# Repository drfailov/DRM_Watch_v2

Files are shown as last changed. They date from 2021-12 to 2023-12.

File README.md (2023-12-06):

<!-- For new line: \ -->
<!-- Picture: <img src="Photos/" width="300"/>  -->

# About project DRM Watch v2
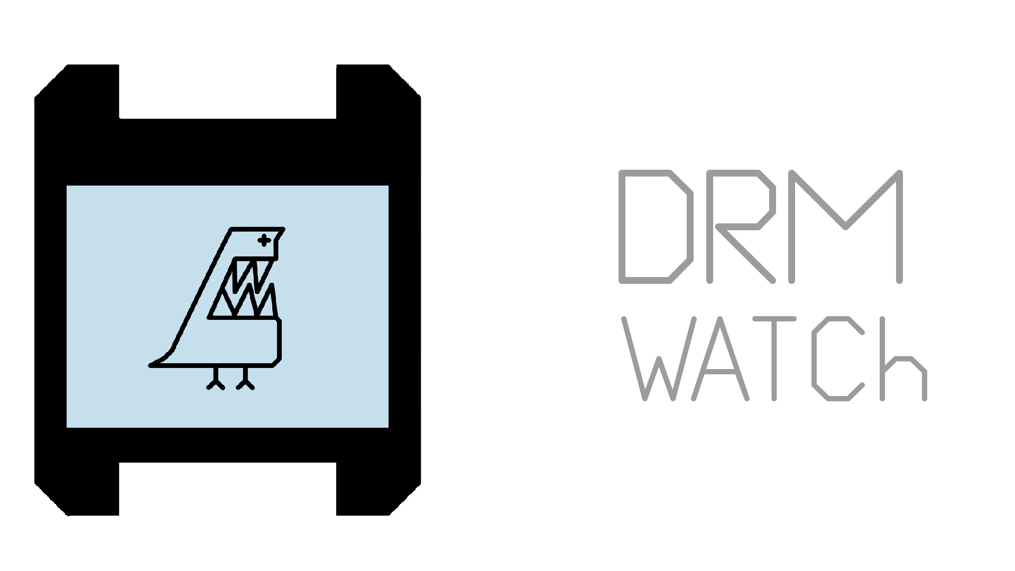
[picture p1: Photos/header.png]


Arduino-based watch with Nokia 1280 LCD. \
Main challenge of this project is packing as much
as possible stuff inside Arduino Nano with its 32KB of memory and 2KB RAM.\
Programming contributions made by <b>Dr. Failov</b>.
<!--Hardware design is made by <b>MeltemiOS</b>. -->

## About project > Features
- Low power consumption, while screen is always showing time;
- Charging over USB, battery status indication;
- Easy to get components needed to assemble;
- For now firmware is stable enough to use device daily;
- Case fits to default 20mm watch bands;
- No need to disassemble device for firmwate update;
- Device easily can be used as arduino playground: battery powered, equipped with 2 buttons, display, buzzer;
- Water-resistance up to 0 meters :)
- Multiple Watchfaces, can be changed from menu;
- 2-button controlled graphic menu allow access to all functions;
- Alarm, can be set from menu;
- Monophonic melodies, can be used as alarm or played from menu;
- Stopwatch, can be accessed from menu;
- Time can be set from menu;
- Silent mode can be set from menu. Disable all sounds except alarm;
- Sound of pressing buttons can be set from menu;
- If needed, you can reboot watch by long-pressing "Up" button on watchface;
- Flip screen allows you to choose between left-hand and right-hand buttons position;
- Random decision helper: Zrada-Peremoga;
- Screen "About" shows credits and firmware version. Long-press will show you some debug information.

## About project > Photos of device
I have assembled few watches and using it as my everyday watch for over a year. 
My device has battery about 80mAh capacity and works about 5 days for one charge.
Other device with 250mAh battery lasts about 2 weeks for one charge.
According to my tests, time error can't be noticed in 1 mounth perspective: RTC is very precise.

Here's some photos of watches with SLS case: 
<p align="center">
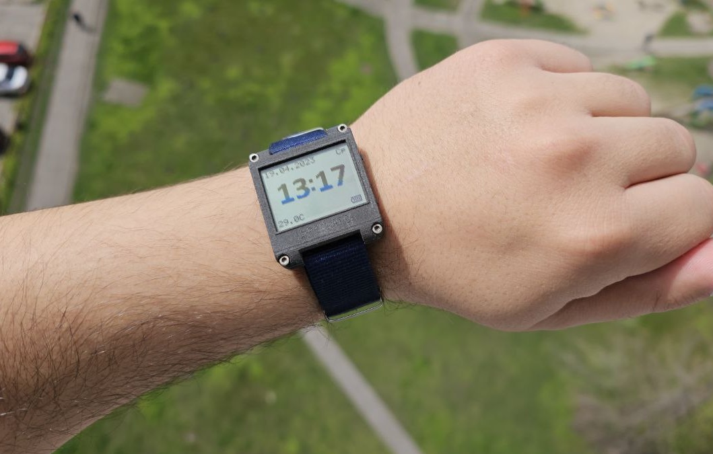
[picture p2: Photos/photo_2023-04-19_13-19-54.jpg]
 
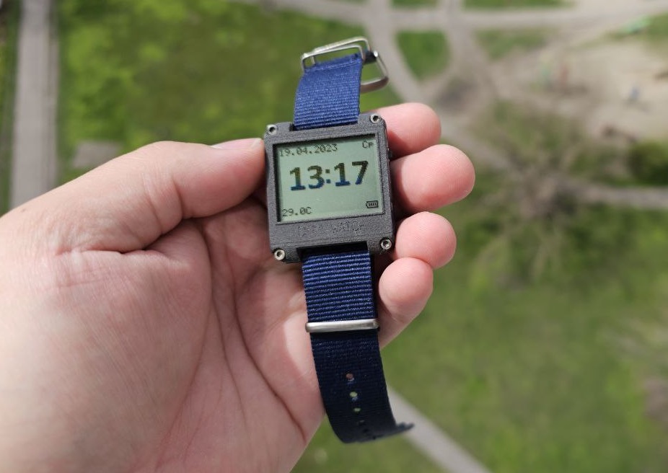
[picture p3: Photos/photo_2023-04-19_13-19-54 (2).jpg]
 
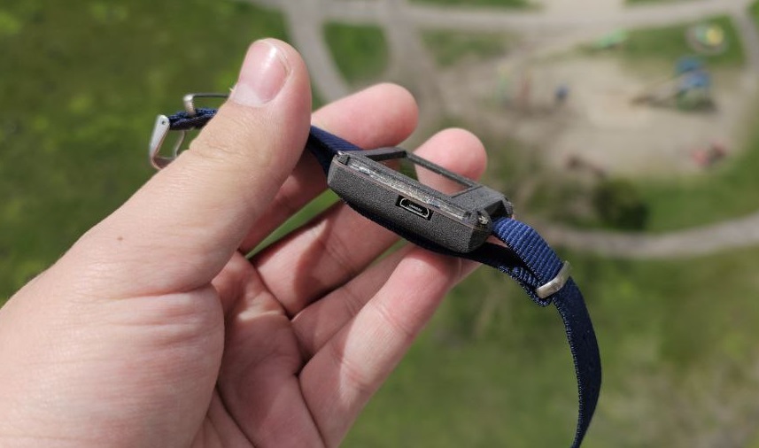
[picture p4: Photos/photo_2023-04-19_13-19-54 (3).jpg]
 
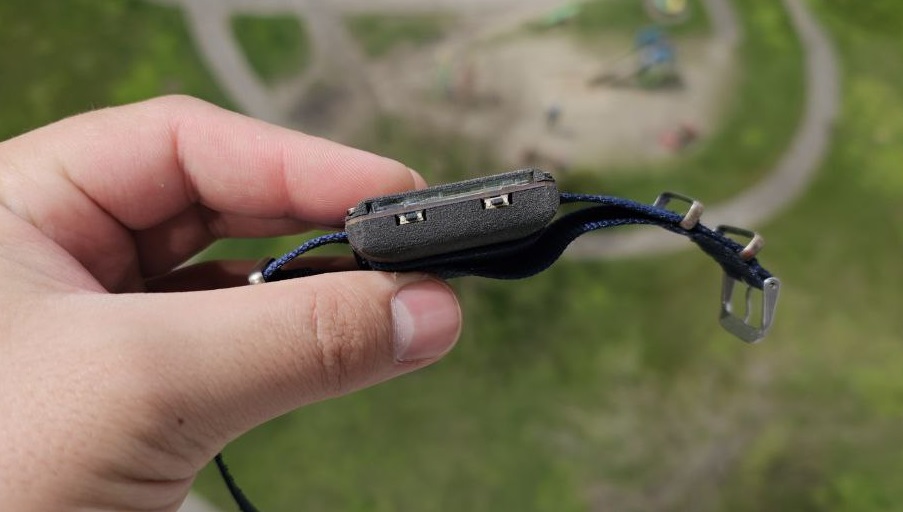
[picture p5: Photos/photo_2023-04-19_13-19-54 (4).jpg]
 
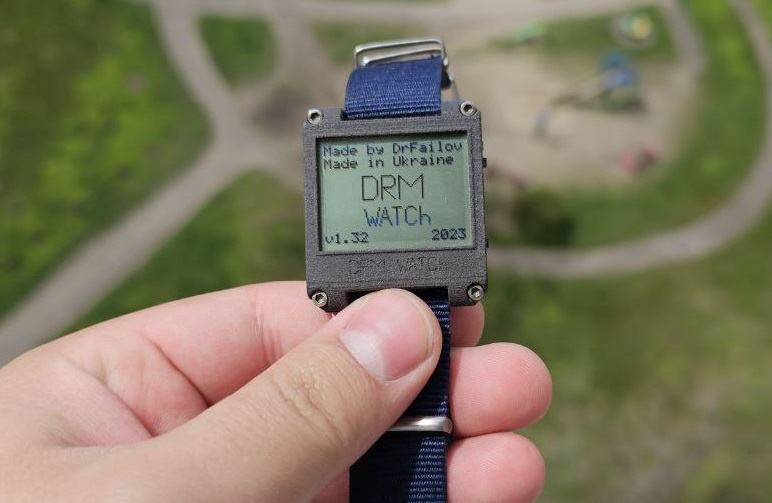
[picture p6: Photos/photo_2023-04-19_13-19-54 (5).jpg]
 
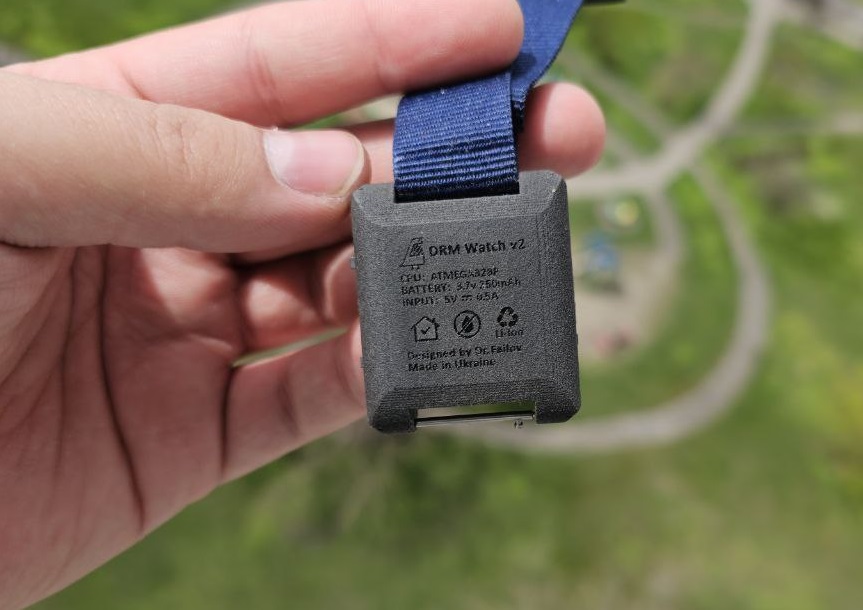
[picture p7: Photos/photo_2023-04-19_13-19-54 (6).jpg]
 
</p>

And some photos of watches with FDM case:
<p align="center">
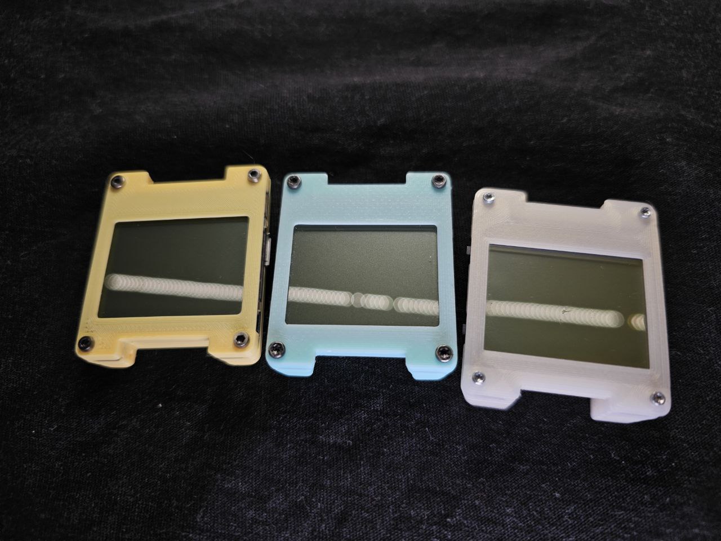
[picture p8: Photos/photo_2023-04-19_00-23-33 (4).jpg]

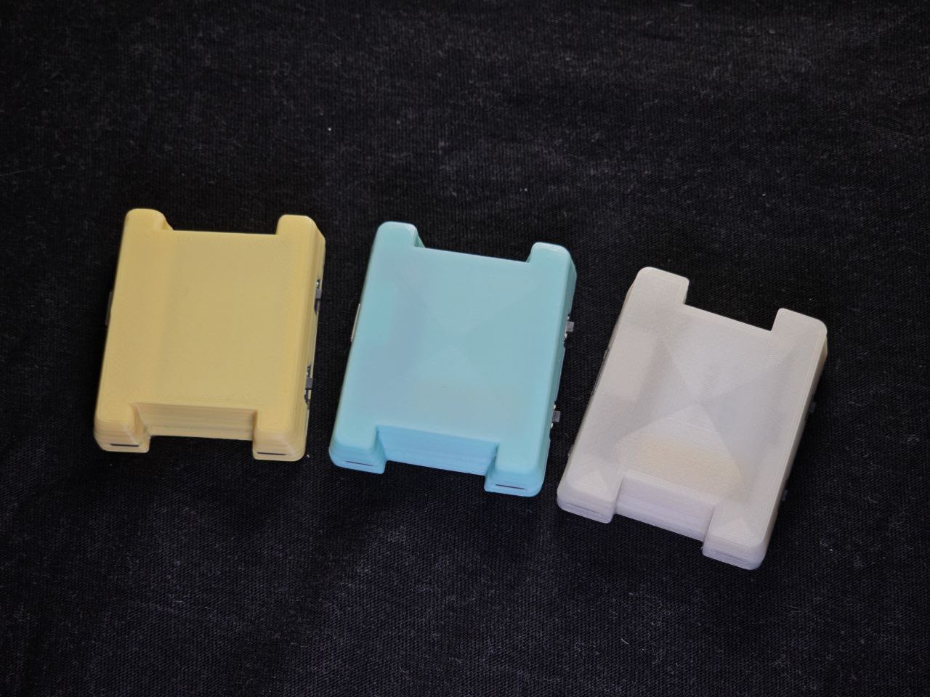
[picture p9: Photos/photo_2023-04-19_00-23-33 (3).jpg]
 
</p>

## About project > Video overview
YouTube video with device overview: 

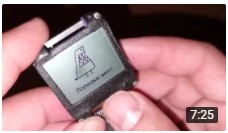
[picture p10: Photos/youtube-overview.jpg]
DRM Watch v2 Overview
[](https://youtu.be/VYrUO039QUw) 
<p align="center">https://youtu.be/VYrUO039QUw </p>

## About project > Typical problems
Regarding watches: they have two typical problems.
1) Water. There is essentially no protection against water, so you need to avoid getting water on them, and especially inside.
2) Statics. Static can occur when plugged into a charger, or when putting on/taking off a sweater or other synthetic clothing.
Therefore, the watch must either be removed for a while, or move slowly so that static in large quantities does not have time to form.

If static has already affected the clock, then:
- usually the display suffers first, there are artifacts. For six months, I had this happen 5 times. 
In this case, the watch can be reset (hold down the top button until you see the loading animation).
- A complete freeze of the controller may occur up to the impossibility of rebooting. 
Then you need to disassemble the watch and reconnect the battery, or wait for the battery to be FULLY discharged and then charge the fully discharged watch.
In the meantime, time will slip. (In my six months of use, this was 1 time).
- The controller may also be affected. (in theory, in practice I haven’t had this for half a year of use)
In this case, it needs to be replaced with a new one (solder the microcircuit)

## About project > Overview of Watchfaces
You can change set of watchfaces in firmware. More info about it in "Software" block.

### Watchface "DRM Watch"
The first watchface in project, back from 2016. Inspired by iPod nano. 
Takes about <b>486 bytes</b> of FLASH memory. 
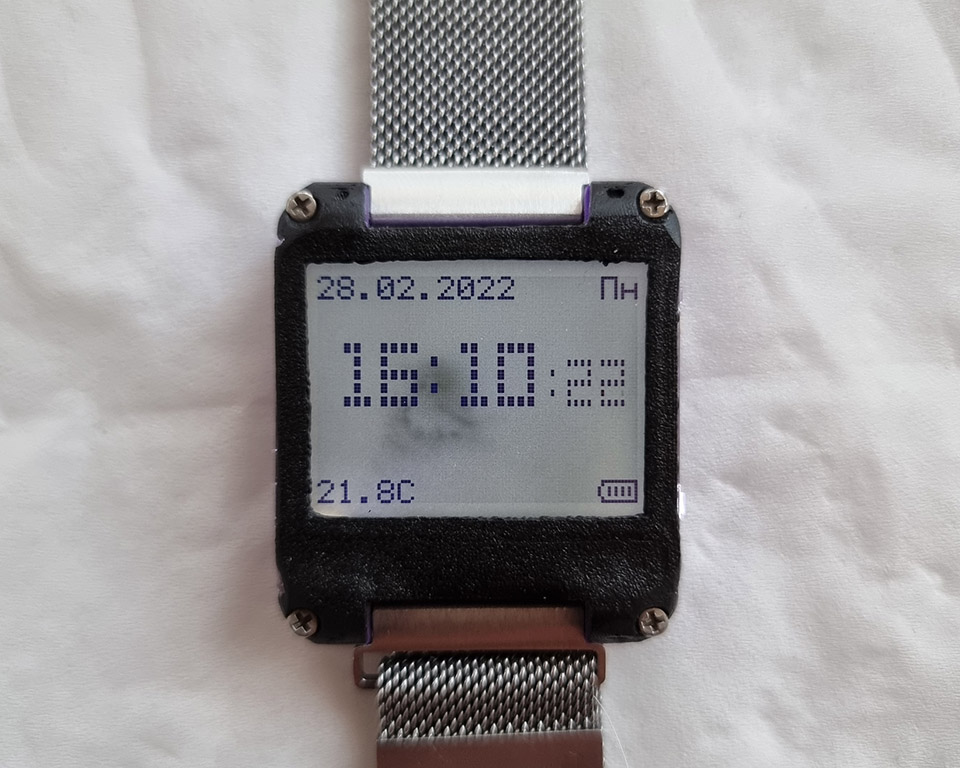
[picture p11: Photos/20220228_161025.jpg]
<p align="center">
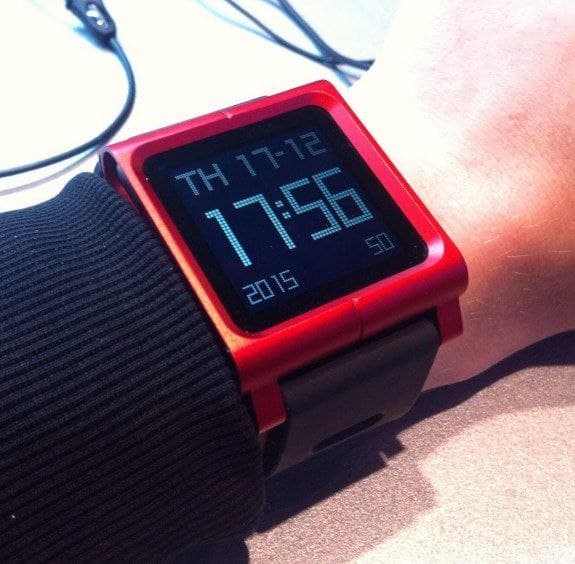
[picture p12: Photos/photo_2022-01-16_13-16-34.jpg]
</p>

### Watchface "DRM Lite"
"DRM Watch" without seconds. \
Designed by <b>Dr. Failov</b>.
Takes about <b>430 bytes</b> of FLASH memory. 
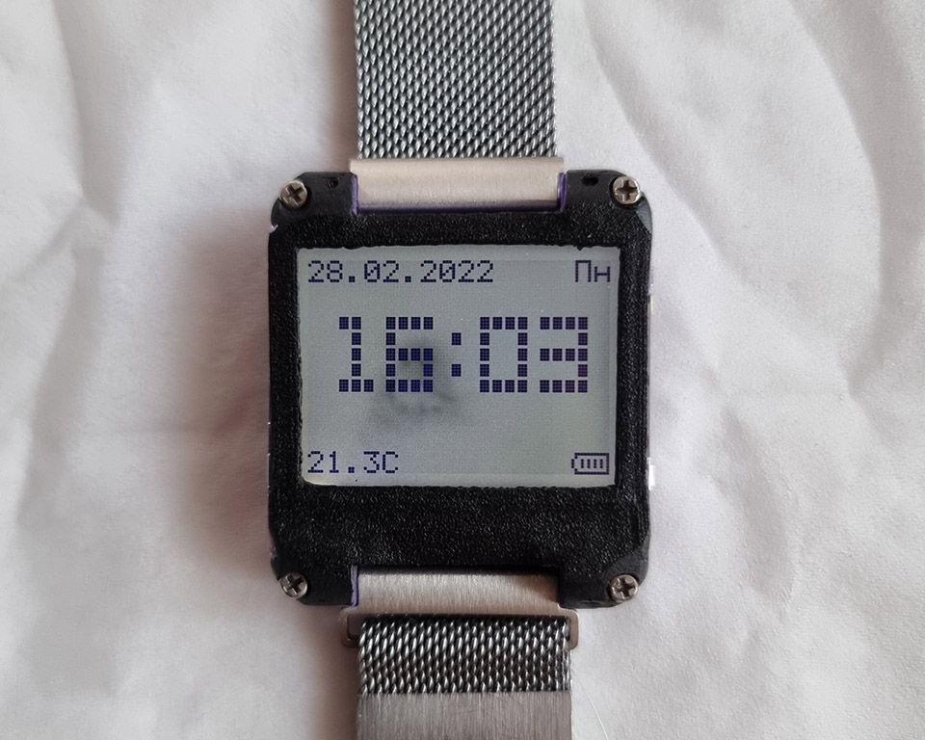
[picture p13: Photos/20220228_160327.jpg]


### Watchface "Nomens"
Inspired by Siemens screensaver and Nokia home screen.
Takes about <b>666 bytes</b> of FLASH memory. 
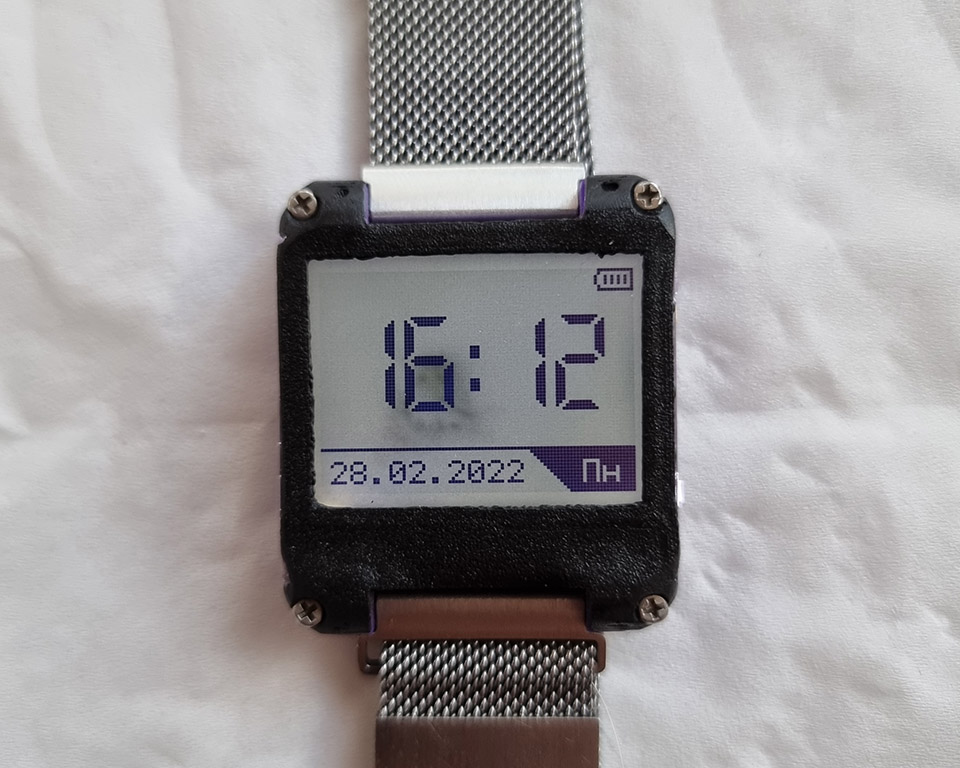
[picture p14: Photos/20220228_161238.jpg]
<p align="center">
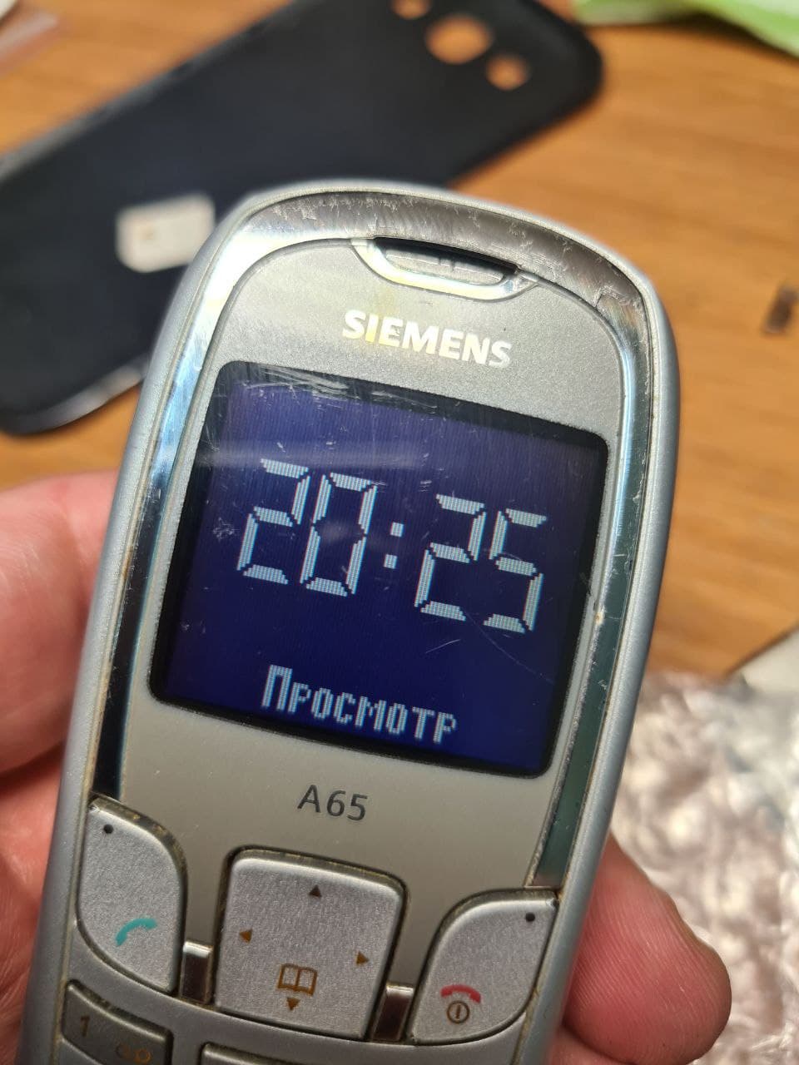
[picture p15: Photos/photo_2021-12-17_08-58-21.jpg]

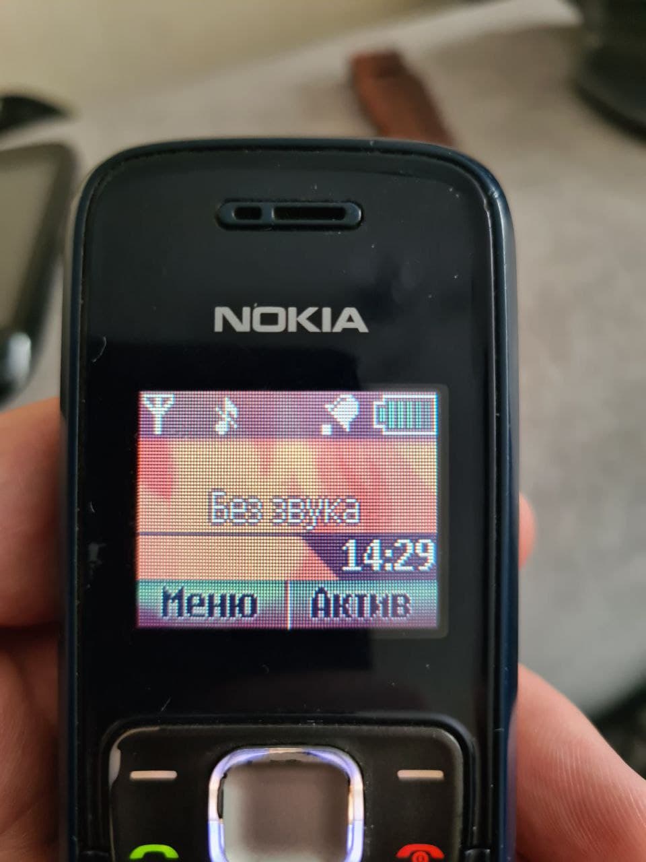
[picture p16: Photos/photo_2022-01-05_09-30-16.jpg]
</p>

### Watchface "Zubat"
Project logo on watchface.\
Designed by <b>Dr. Failov</b>.
Takes about <b>336 bytes</b> of FLASH memory. 
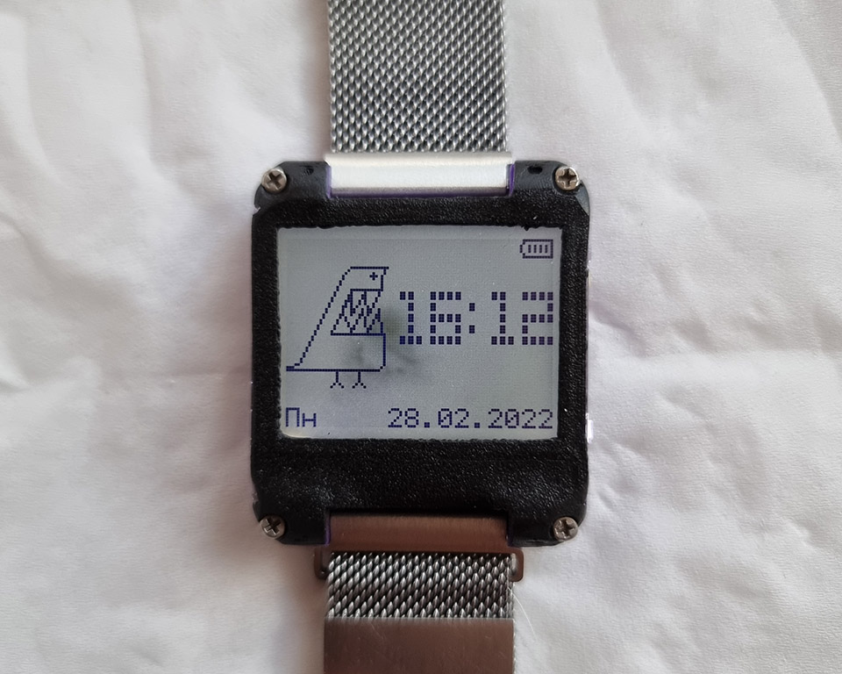
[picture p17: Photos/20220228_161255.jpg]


### Watchface "Xelibri"
Inspired by Siemens Xelibri product line. Very memory-hungry watchface.
Takes about <b>1528 bytes</b> of FLASH memory. 
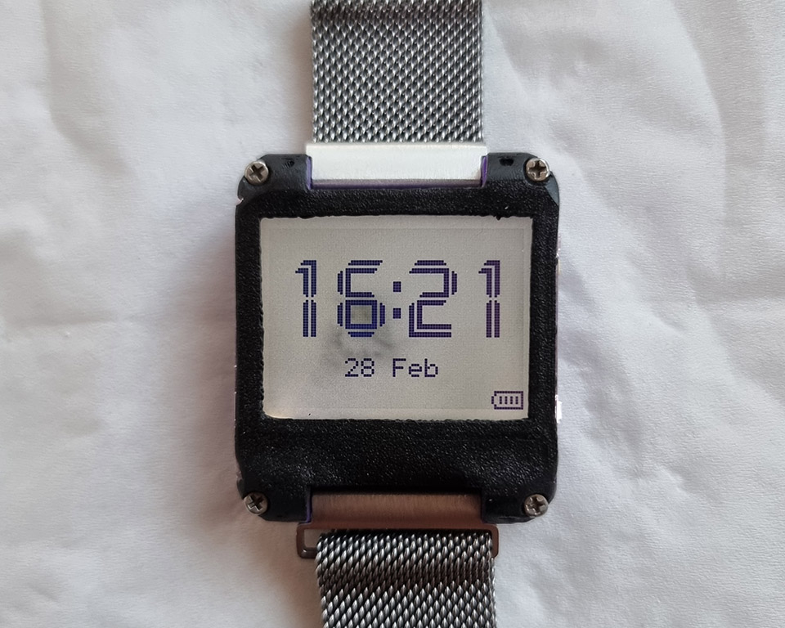
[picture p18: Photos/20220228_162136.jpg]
<p align="center">
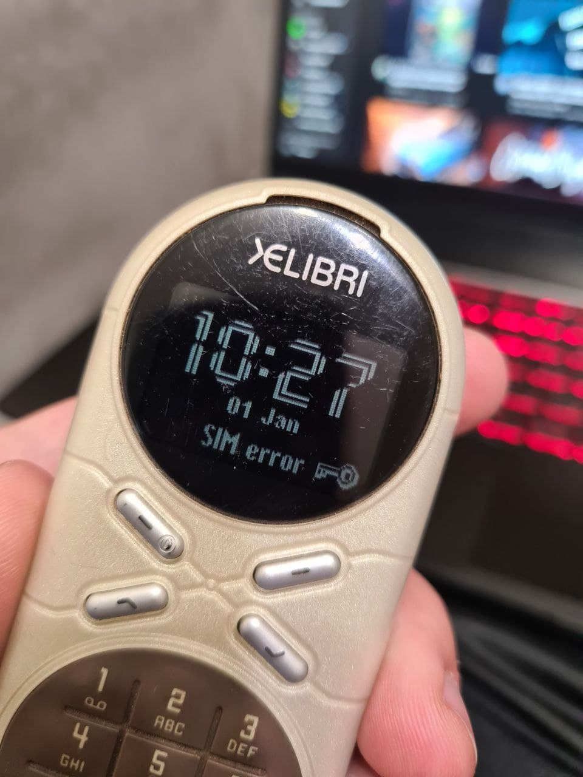
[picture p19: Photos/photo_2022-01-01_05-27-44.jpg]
</p>

### Watchface "Matrix"
Inspired by Matrix film, like font on secret documents.
Takes about <b>886 bytes</b> of FLASH memory. 
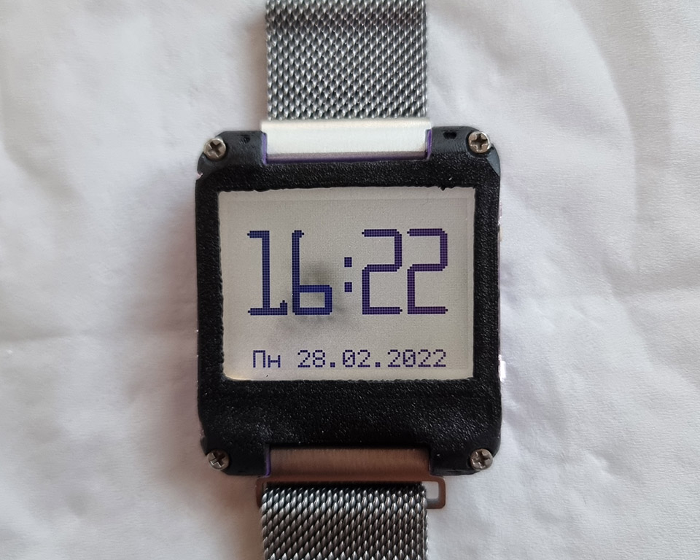
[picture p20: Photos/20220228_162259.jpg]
<p align="center">
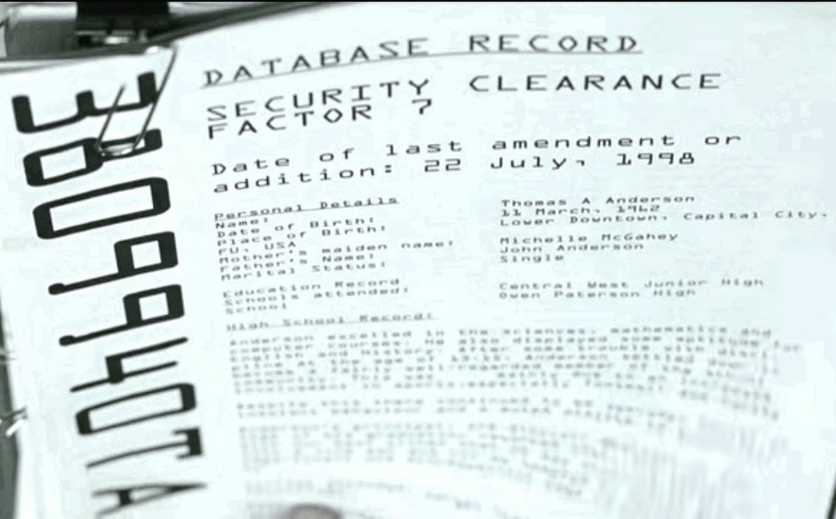
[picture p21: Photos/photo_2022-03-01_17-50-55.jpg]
</p>

### Watchface "Minimal"
Shows only time. Press DOWN button to show more info.
Takes about <b>446 bytes</b> of FLASH memory. 
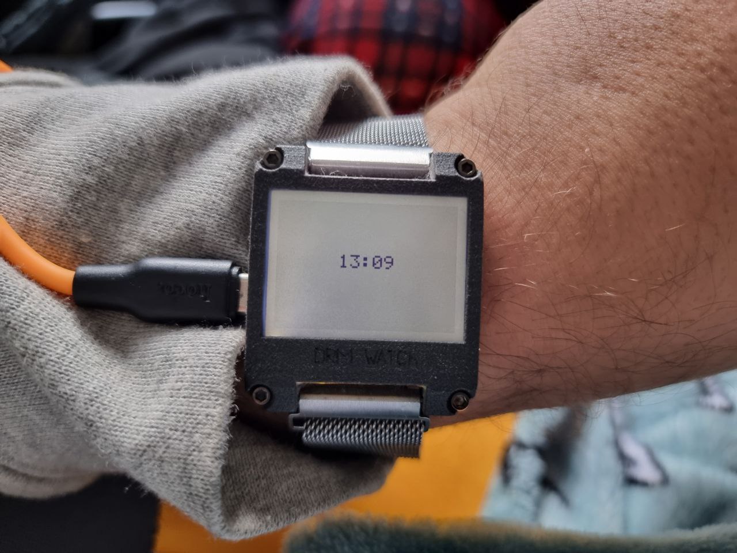
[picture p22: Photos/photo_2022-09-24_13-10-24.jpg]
<p align="center">
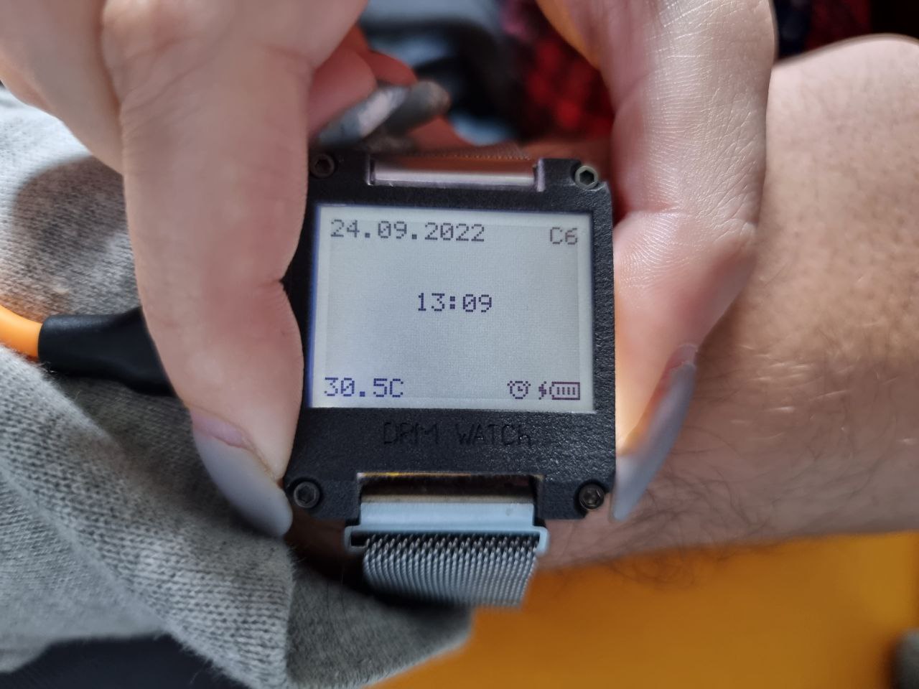
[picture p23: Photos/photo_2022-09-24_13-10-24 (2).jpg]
</p>

### Watchface "Life"
Conway's Game of Life as background.\
Designed by <b>Dr. Failov</b>.
Takes about <b>684 bytes</b> of FLASH memory. 
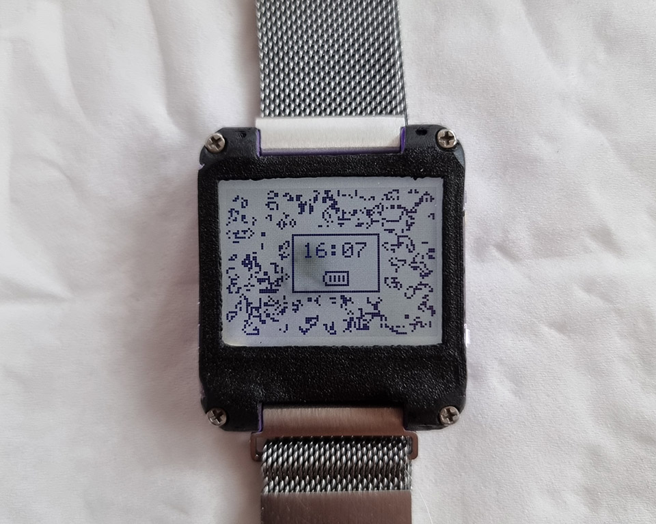
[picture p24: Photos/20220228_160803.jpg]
<p align="center">
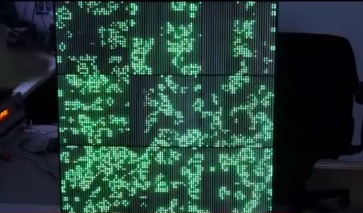
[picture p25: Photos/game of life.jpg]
</p>

### Watchface "Calibri"
Simple but informative watchface with font "Calibri".\
Designed by <b>Dr. Failov</b>.
Takes about <b>1340 bytes</b> of FLASH memory. 
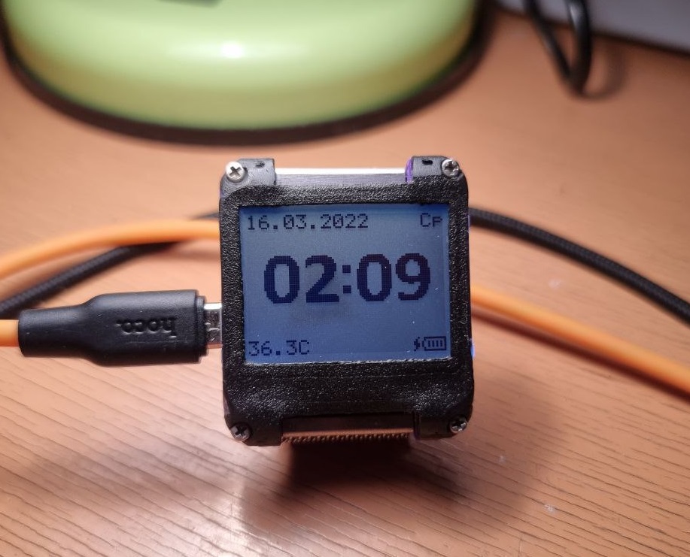
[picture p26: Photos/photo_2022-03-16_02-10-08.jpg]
<p align="center">

### Watchface "Thermo"
The only information shown is temperature with font "Calibri". Very memory-hungry watchface.\
Designed by <b>Dr. Failov</b>.
Takes about <b>1466 bytes</b> of FLASH memory. 
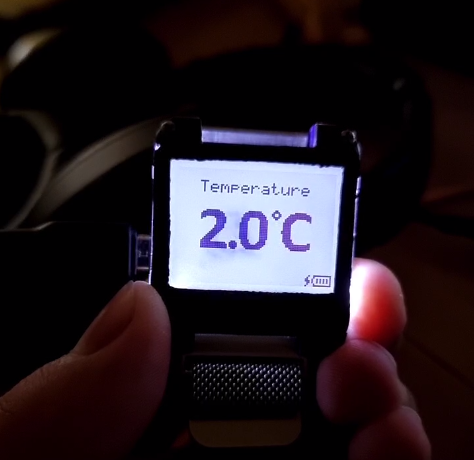
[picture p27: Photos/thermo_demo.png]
<p align="center">

## About project > Overview of screens
Here's detailed overview of every screen and mode with recomendations how to use it.
You also can add your own screens, more info about it in "Software" block.

### Init screen
Initial mode. Its goal to init Serial, init display, init RTC, show startup animation, and go to watchface.
Current firmware version is shown on this screen.
If RTC can not be initialized, watchface will not open.
No user input on this screen.
<p align="center">
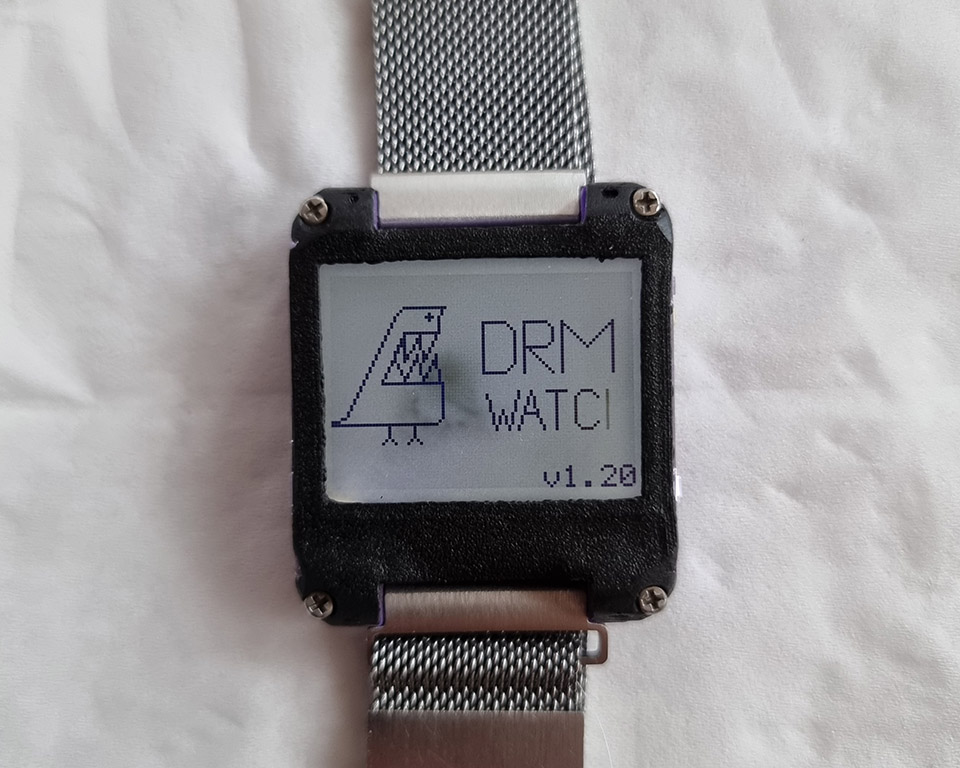
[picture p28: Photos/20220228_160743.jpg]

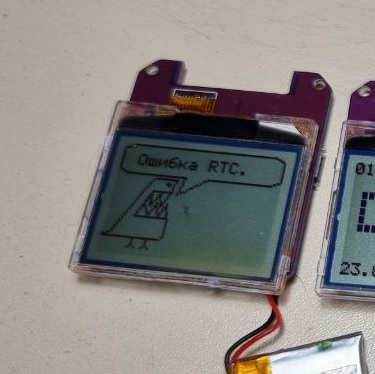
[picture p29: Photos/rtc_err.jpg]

</p>

### Watchface screen
Screen with watchface. 
Watchfaces is only screen with deep sleep, so device can run for a long time if in watchface mode.

First 30 seconds after user input watchface is updating without sleep. After 30 seconds: draws 1 frame in 8 seconds.
When battery is low, 1 frame in 8s sleep is used for any watchface.
- To enter main menu, press <b>up</b> button once. 
- To force reboot watch, hold <b>up</b> button for 3 seconds. 
- To enable backlight for 7 seconds, press <b>down</b> button once. 
- To keep backlight on and continue animation (if any), hold <b>down</b> button. 
<p align="center">

</p>

### Main menu screen
Main menu to access all the features. 
Upper bar contains current temperature (read from RTC), battery status and icons.
Bottom bar contains description of selected item. 
Text available in russian and english. See "Software" block for more.
If inactive for 120 sec, will automatically go to watchface. 
Buttons are indicated on the side of the screen.
- Press <b>up</b> button to confirm selected item.
- Press <b>down</b> button to move cursor down.
<p align="center">
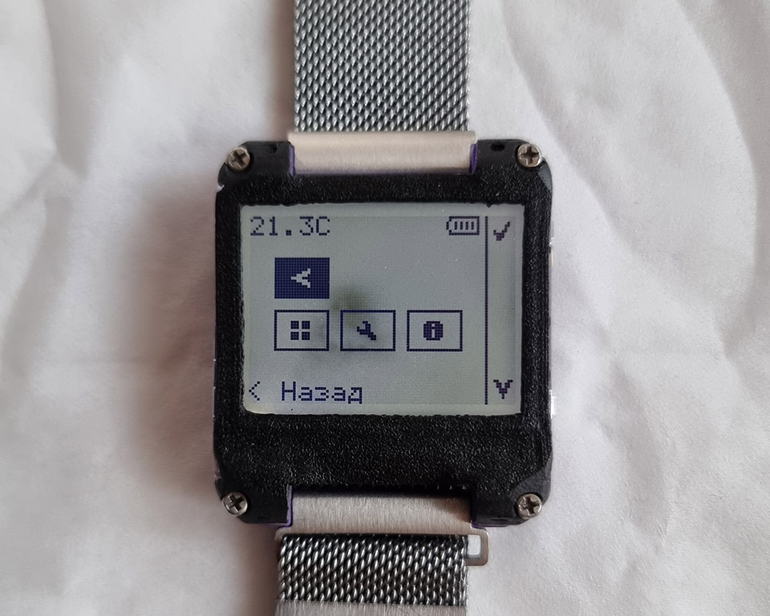
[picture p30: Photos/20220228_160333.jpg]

</p>

### Application list screen
List of useful applications.
Text available in russian and english. See "Software" block for more.
If inactive for 120 sec, will automatically go to watchface. 
Buttons are indicated on the side of the screen.
- Press <b>up</b> button to confirm selected item.
- Hold <b>up</b> button for 3 seconds to go back to watchface.
- Press <b>down</b> button to move cursor down.
<p align="center">
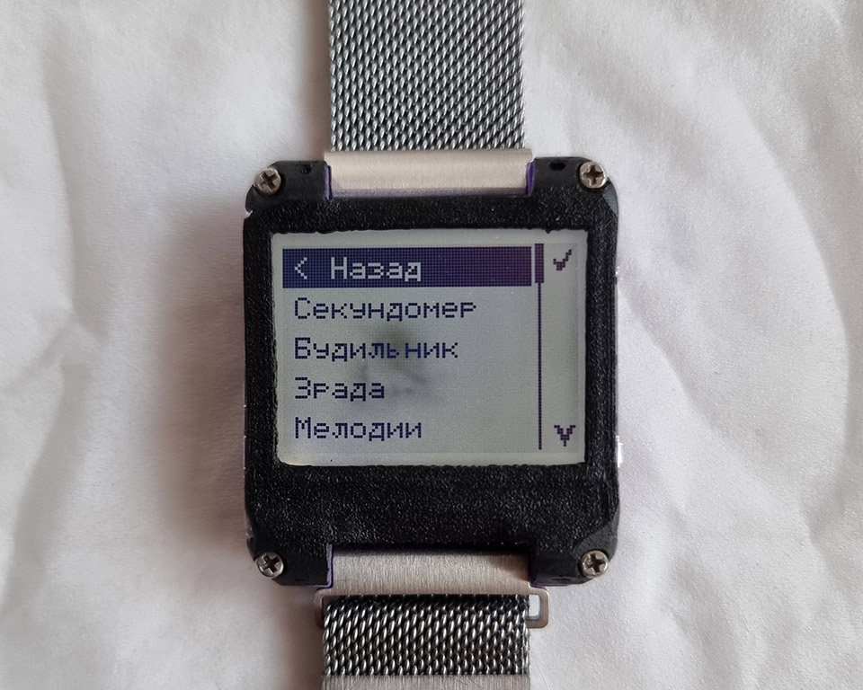
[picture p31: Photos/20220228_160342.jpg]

</p>

### Stopwatch application
Stopwatch designed to measure the amount of time that elapses between its activation and deactivation.
Stopwatch count time only while application is opened due to power consumption reasons.
There is no auto-exit from this menu, so if you leave watch untouched in this mode, it will discharge and power off (time will reset). 

Buttons are indicated on the side of the screen.
- Press <b>up</b> button Start/Pause stopwatch.
- Hold <b>up</b> button to Back to watchface. Stopwatch will reset.
- Press <b>down</b> button to Reset stopwatch to zero value.
<p align="center">
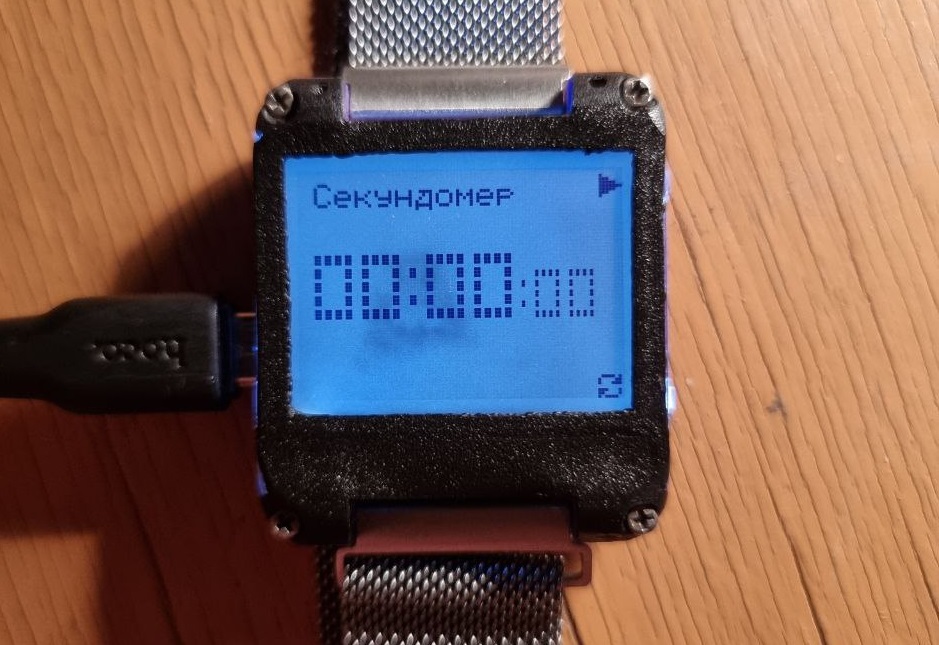
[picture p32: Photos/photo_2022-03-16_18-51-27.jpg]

</p>

### Alarm
You can select time and melody and alarm will play at that time. Alarm will start only if watchface is opened.
There is no auto-exit from this menu, so if you leave watch untouched in this mode, it will discharge and power off (time will reset). 

Menu items is:
- Back to apps list.
- Enable/Disable alarm.
- Alarm hour.
- Alarm Minute.
- Alarm Melody.

Buttons are indicated on the side of the screen.
- Press <b>up</b> button to confirm selected item or increment item.
- Press <b>down</b> button to move cursor down.
<p align="center">
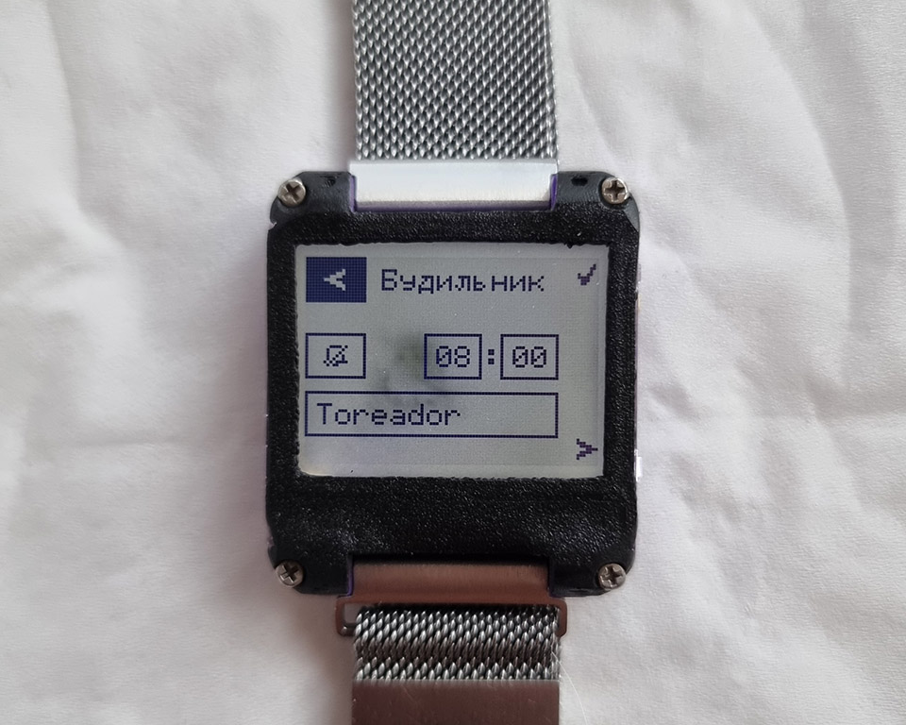
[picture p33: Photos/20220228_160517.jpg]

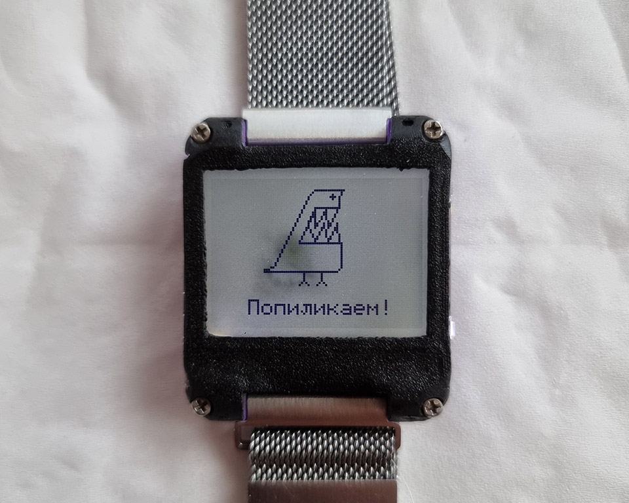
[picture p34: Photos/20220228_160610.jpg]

</p>

### Zrada
Genegates random conscusion: "Peremoga" or "Zrada". This is local Ukrainian meme.
"Peremoga" is "win", "Zrada" is "treason".
Mechanics the same as heads and tails.
There is no user input, after message opens apps list.
<p align="center">
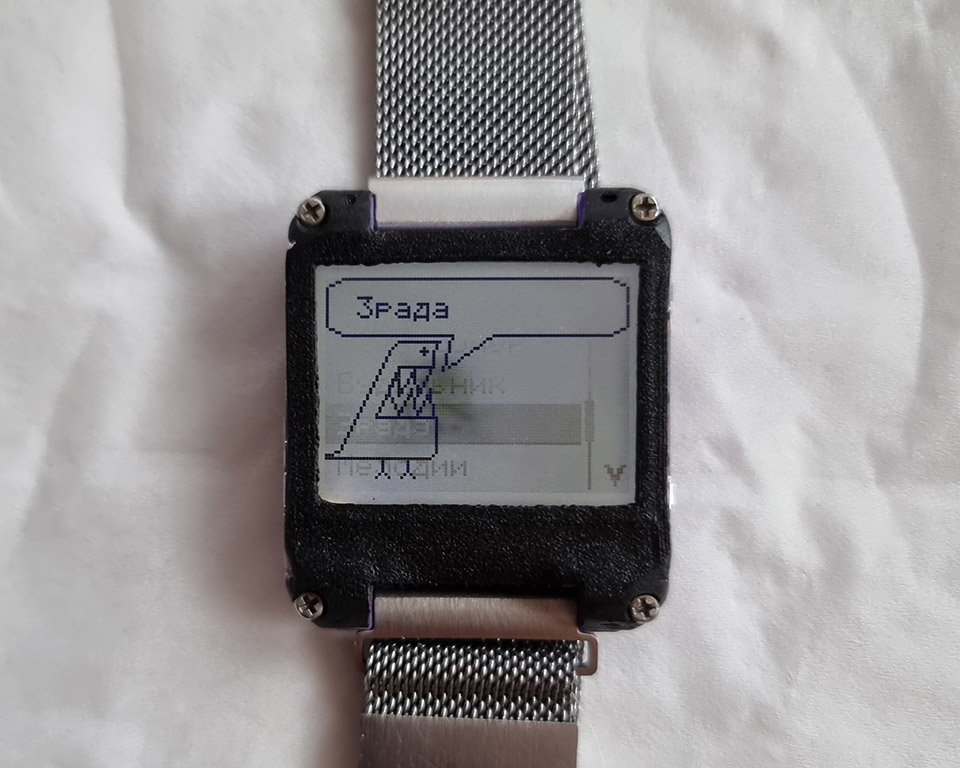
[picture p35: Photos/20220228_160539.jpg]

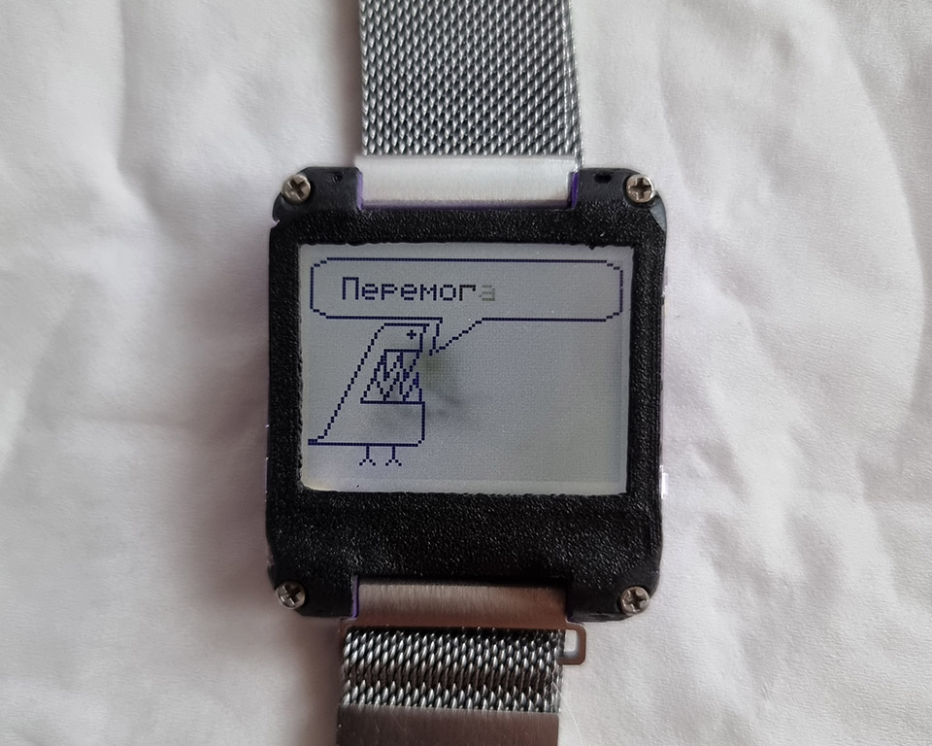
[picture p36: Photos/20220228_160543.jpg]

</p>

### Melodies list
Menu with list of melodies, which can be played.
If inactive for 120 sec, will automatically go to watchface. 
Buttons are indicated on the side of the screen.
- Press <b>up</b> button to confirm selected item.
- Hold <b>up</b> button for 3 seconds to go back to watchface.
- Press <b>down</b> button to move cursor down.\
When melody is playing:
- Press <b>up</b> button to exit back to list.
- Hold <b>up</b> button to loop melody.
There is no auto-exit from melody playing if loop, so if you leave watch untouched in this mode, it will discharge and power off (time will reset).
<p align="center">
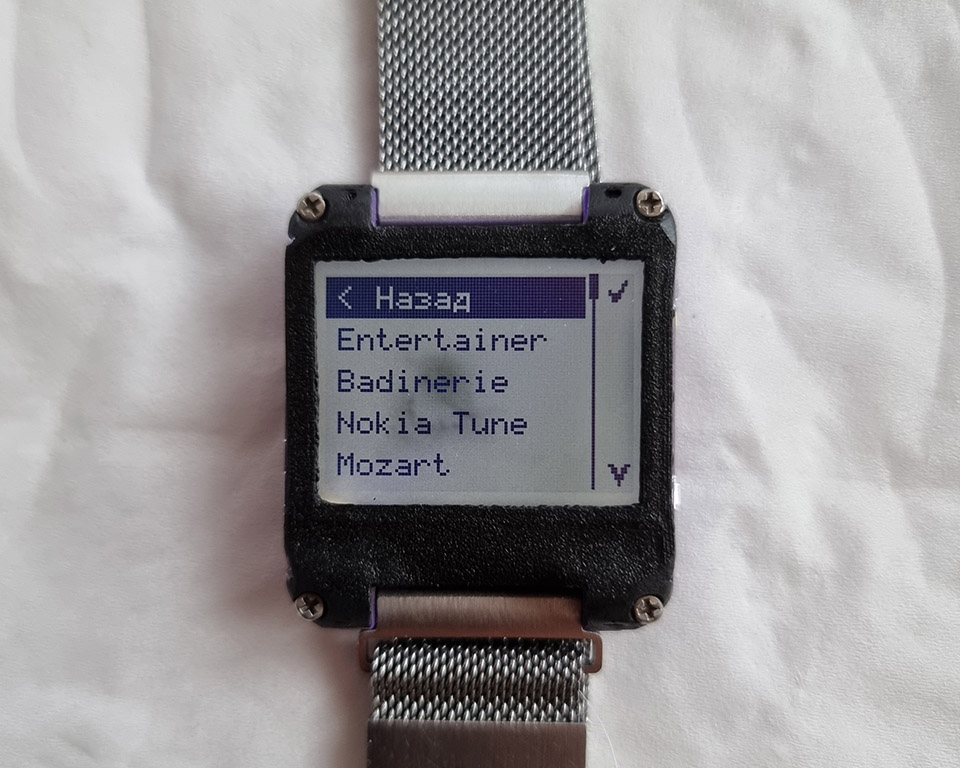
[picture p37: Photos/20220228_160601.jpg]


</p>

### Life
Game of life is a cellular automaton.
There is no auto-exit from this menu, so if you leave watch untouched in this mode, it will discharge and power off(time will reset).
- Press <b>up</b> button to fill screen with random pattern.
- Hold <b>up</b> button to exit to watchface.

### Meow
Watch will meow until you stop it.
There is no auto-exit from this menu, so if you leave watch untouched in this mode, it will discharge and power off(time will reset).
- Press <b>up</b> button to exit to watchface.

### Settings screen
Main place where you can change parameters of wor DRM Watch.
If inactive for 120 sec, will automatically go to watchface. 

Menu items is:
- Back to main menu.
- Enable or disable silent mode. In silent mode watch will not play any sound except alarm.
- Flip screen. 
You can select optimal screen orientation for wearing watch on left or right hand. 
Every screen and application will adapt to selected screen orientation.
- Watchface selection.
You can choose watchface from list of watchfaces you included in firmware.
If watchface count set incorrectly, "-" option can appear in list.
If no watchface is included in firmware, "Select WTF" text will appear on watchfaces screen.
- Sound on keypress. 
There are different options for buttons sound: beep, click, tone, whistle, none.
After changing value you can immediately hear new sound.
- Set time and date.

Buttons are indicated on the side of the screen.
- Press <b>up</b> button to confirm/change selected item.
- Hold <b>up</b> button for 3 seconds to go back to watchface.
- Press <b>down</b> button to move cursor down.
<p align="center">
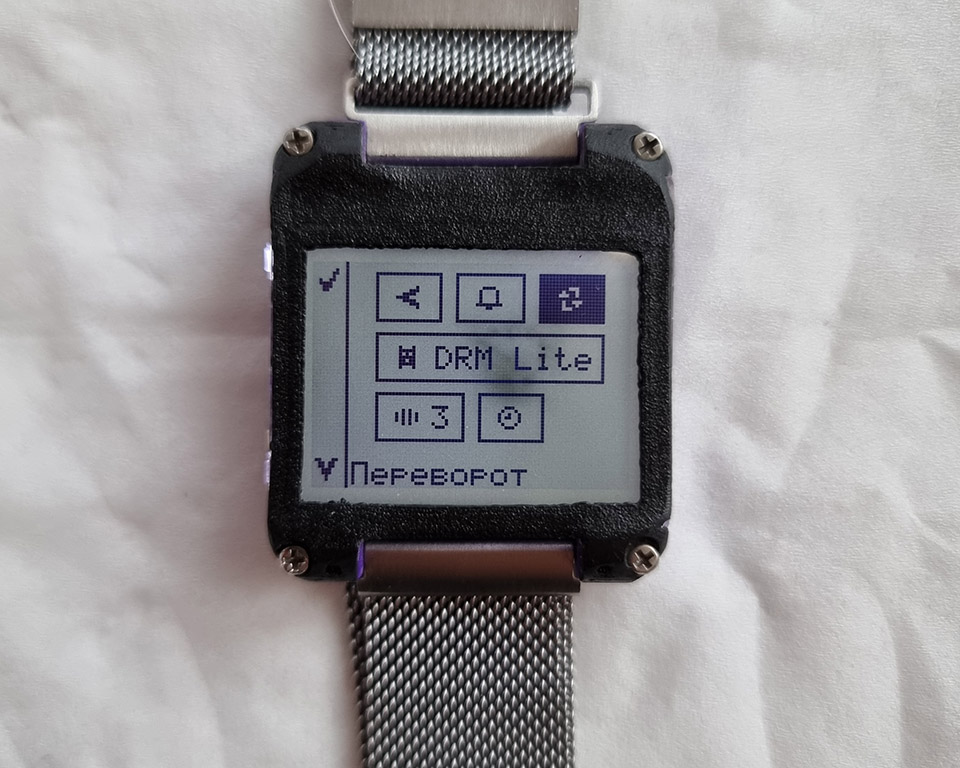
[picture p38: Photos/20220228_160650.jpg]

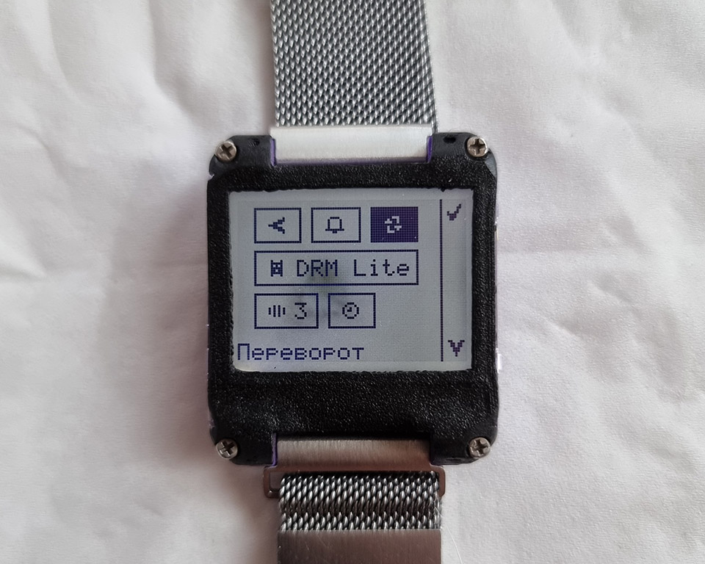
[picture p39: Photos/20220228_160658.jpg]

</p>

### Time setting screen
Menu to set correct time manually. 
There is no auto-exit from this menu, so if you leave watch untouched in this mode, it will discharge and power off (time will reset).
Time is storing in RTC while RTC is powered. If battery is discharged and watch power off, time will reset.
To prevent resetting time you can attach backup power to RTC's Vbat according to its datasheet.

Menu items is:
- Back to settings list.
- Current hour.
- Current minute.
- Current day of month.
- Current month.
- Current year (20xx).
- Save values: write data to RTC.

Buttons are indicated on the side of the screen.
- Press <b>up</b> button to confirm/change selected item.
- Press <b>down</b> button to move cursor down.
<p align="center">
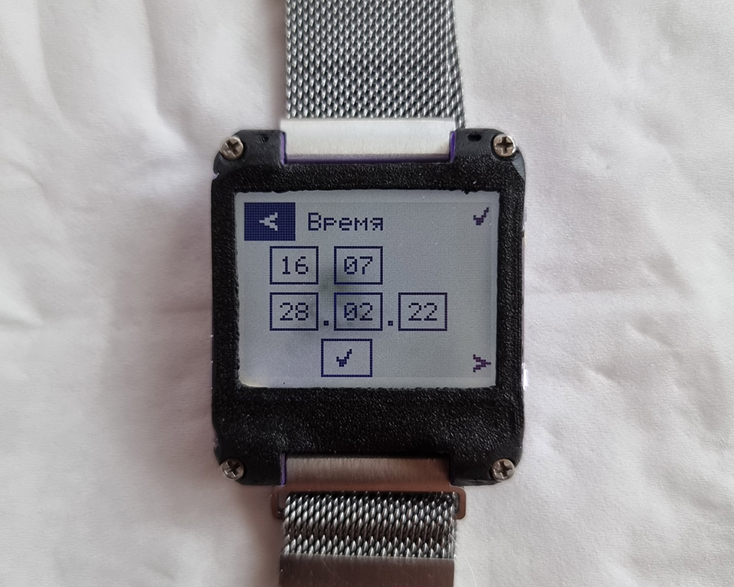
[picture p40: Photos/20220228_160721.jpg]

</p>

### "About" screen
Information about developers and firmware version.
If inactive for 120 sec, will automatically go to watchface. 

Buttons:
- Press <b>up</b> button to go to watchface.
- Hold <b>up</b> button for 3 seconds to go to debug screen.
<p align="center">

</p>

### Debug screen
Technical status information about system.
Also, technical information is indicated in Serial logs.
There is no auto-exit from this menu, so if you leave watch untouched in this mode, it will discharge and power off (time will reset).

Information shown:
- `VLT`: Current battery voltage detected by Arduino.
Allows to check if voltage reading is correct and calibrate values if needed.
Value interpreting is 4092 = 4.092v.
Also this value indicated in battery indicator, but in form of bars.
- `RAM`: Remaining free RAM in runtime. 
To prevent overfilling while implementing new functions.
Value is in bytes. Also this value indicated in serial log when mode changes.
- `CHG`: Status of connected charger. 
Helps debug charger detection.
1 means charger connected, 0 means no charger connected.
Also this value indicated on battery indicator as lightning near icon.
- `aLD`: Last day (of month) when alarm was run.
Helps to debug alarm and process behavior on "empty" brand new Arduinos without any settings.
Value is important because it is not indicated anywhere else.
- `WTF`: Current value of selected watchface index.
System has protection in case of incorreclty set watchface number, 
so only way to get know about data in memory is this value.
Helps to process behavior on "empty" brand new Arduinos without any settings.

Buttons:
- Press <b>up</b> or <b>down</b> button to go to watchface.
<p align="center">

</p>

# Hardware

If you want to assemble your own DRM Watch, this block is for you:)
To assemble watch, you will need: <b>circuit board, parts or modules to desolder, case</b>. 
Also, some instruments, much time and some experience.

## Hardware > Used parts
- Arduino Nano (MEGA328P chip)
- Nokia 1280 LCD (PCF8814 chip)
- RTC module (DS3231M chip)
- Li-Po charger module (TC4056A chip)

To get components I've desoldered modules. 
Why desoldering instead of buying components separately?
Because I had a lot of situations when received defective chips out of the box.
Buying modules can be more expencive, but more reliable.
<p align="center">

</p>

### Arduino Nano, CH340C and MEGA328P
MEGA328P used as main controller.\
CH340C Is needed to allow programming with USB port.\
Link: https://aliexpress.ru/item/4000903444456.html  
<p align="center">


</p>

### Nokia 1280, PCF8814 LCD
Also, this display is used in: Nokia 1202, Nokia 1280, Nokia 1203.
And also compatible with Nokia 1100 LCD, Nokia 1101 LCD, Nokia 1110 LCD, but it will not fit with board.
Display is main output device. \
Link: https://aliexpress.ru/item/32864378445.html  
<p align="center">


</p>

### RTC module, DS3231M chip
DS3231M is needed to precisely calculate time. \
Link: https://aliexpress.ru/item/4000004876793.html  
<p align="center">



</p>

### Passive buzzer, 5.2mm x 5.2mm 
Buzzer allows to play sound signals and melodies. \
Link: https://aliexpress.ru/item/1005003227004618.html  
<p align="center">



</p>

### Board
I've ordered boards on JLC PCB. Actual version of gerber files to make your order see at `Circuit Board` folder. \
Here's what I got: 
<p align="center">
 
 
 
</p>
<p align="center">(It's older revision on photo) </p>

## Hardware > Schematics
### Board gerber files
You can fing GERBER files for DRM Watch board in `Circuit Board` folder. Case is designed to fit <b>1mm thick</b> board.
<p align="center">

</p>

### Board soldering plan, elements list
Description of elements on board:
<p align="center">


</p>

### Atmel 328P chip pinout
You can use this schematic as reference. 
<p align="center">

</p>

Used pins:
- D0 - UART RX
- D1 - UART TX
- D2 - Button DOWN (Active HIGH)
- D3 - Button UP (Active HIGH)
- D5 - LCD RST
- D6 - LCD CS
- D7 - LCD MOSI
- D8 - LCD SCK
- D9 - not used
- D10 - LCD Power
- D11 - USB Voltage    
- D12 - Buzzer (Passive)
- D13 - Debug LED
- A1(D15) - LCD Backlight (Active HIGH)
- A4 - RTC SDA
- A5 - RTC SCL

## Hardware > Case 3D Model
You can fing STL files for DRM Watch case in `Case` folder. 
There's 2 types of case available. 
You can edit both of my cases for you, use my Fusion 360 project: `DRM Watch v85.f3d`.
<p align="center">



</p>

One is more fancy, but can't be printed on FDM printer, better is to order SLS printing. 
You can fing use files `2022-10-12 Back v38.stl` and `2022-10-06 Front v35.stl`.
<p align="center">


</p>

Second is adapted to FDM printing. Now it's files `Front Case FDM v85.stl` and `Back Case FDM v85.stl`.
<p align="center">


</p>
Video overview of this case you can see here:
https://www.youtube.com/watch?v=uoMRFqTGYNg

## Hardware > Assembly instruction
### General way to assemble watch:
- Order PCB using `gerber` files, Get all [parts you needed](Photos/photo_2022-01-11_15-28-52.jpg), desolder modules;
- At first, solder parts from Arduino and Lipo charger modules, Double-check all the connections, especially for shorts between chip pins, Let board cool down before testing;
- Connect battery and check if no fire or heat from PCB, Connect charger and check current. Normal value is about 200mA (or about 1A if you did not replacd 1.2K resistance), Don't connect USB without battery - board will not work this way.
- Connect board to USB. If modules works properly, PC will recognize CH340G as connected device;
- If needed, install driver for CH340G: https://drive.google.com/file/d/1BqUo6f5WEd1vqdxt1UWzDh4OgjdQ7Mx1/view ;
- If needed, install Arduino IDE: https://www.arduino.cc/en/software ;
- Copy libraries to your Arduino IDE libraries folder;
- Build project and try to flash firmware. If [flashing successful](Photos/photo_2022-02-17_21-01-05.jpg), you can continue. [Normal log for this state](Photos/photo_2022-02-17_21-01-24.jpg) ;
- Now you can solder RTC, buttons, buzzer, LCD. [Photo](Photos/photo_2022-02-17_22-31-56.jpg) ;
- If successful, watch will turn on, play sound and [show time](Photos/photo_2022-02-17_22-41-40.jpg);
- If any of functions is not working, always keep in mind that any module can be defective out of the box, so you need to have spare ones to replace;
- If all works, carefully wash flux all over the board.
- Now you can assemble device to case and start using it :)

### Here's some photos of assembly process:
<p align="center">
 
 

 
 

 
 


</p>

### Assembly video on YouTube:
[<p align="center">DRM Watch v2 Assembly </p>](https://youtu.be/IrAri0zF-KY)
<p align="center">https://youtu.be/IrAri0zF-KY </p>

## Hardware > Troubleshooting

### No any activity after connecting battery
- Battery protection is blocking power. Connect to USB or charger to start BMS.
- Connect charger and check for current by USB Charger Doctor. Correct value is about 200-600mA.
- Check if battery protection ICs soldered in correct orientation.
- Check voltage on Arduino.
- Replace battery protection ICs and its related components.

### No device connected or Unrecognized device on PC when USB connected
- Check if CH340 is soldered in correct orientation. 
- Check or replace resonator (if any). 
- Check USB wiring.
- Check if USB contacts is dirty.
- Wipe flux from USB port.
- Check for shorts between chip pins.
- Replace CH340 and its related components.

### No response from board when trying to flash firmware.
- Check if Atmel328 is soldered in correct orientation.
- Check your Arduino. (if pin13 LED is blinking when power on, arduino is alive) 
- Check wiring from CH340 to Atmel328.
- Check if resistance for UART line is not broken.
- Check if capacitance for RESET pin is not broken or shorted.
- Check for shorts between chip pins.
- Wipe flux from board.
- Replace CH340 and Atmel328 and its related components.

### Arduino is not working, pin13 LED is not blinking
- Check if Atmel328 is soldered in correct orientation.
- Check if battery is connected. Device will not work without battery.
- Check if Atmel328 is OK at all: if it was working on original Arduino board.
- Check for shorts between chip pins.
- Check or replace resonator (if any). 
- Wipe flux from board.
- Replace Atmel328 and its related components.

### RTC FAIL on startup
- Check if RTC is soldered in correct orientation.
- Check if resistance for i2c line is not shorted or broken.
- Check if power is present on RTC chip.
- Check for shorts between chip pins.
- Wipe flux from board.
- Replace RTC and its related components.

### Select WTF After flash firmware
- Check if watchfaces count set correctly
- Check if watchfaces is included in firmware. 
- Add or uncomment watchfaces and flash again.

# Software
Description of software components and how to build.

## Software > Firmware versions
There are different versions of firmware with different purposes.

### _DRMWatch2
Main version, full functionality, full memory usage.
<p align="center">

</p>

### _DRMWatch2_MinimalEdition
Functional version available for daily use, but totally reduced memory usage. 
You can use it for write your own applications for watch.
<p align="center">

</p>

### _DRMWatch2_FactoryTest
Just testing hardware, you can use it to build your own firmware from scratch.
<p align="center">

</p>

## Software > Used libraries
### LCD1202
Used to run nokia display. Also may be compatible with this LCD controllers: `pcf8814`, `ste2007`, `ST7565`, `HX1230`.
Library included in this repo. Just copy it to your libraries folder (`C:\Users\USER\Documents\Arduino\libraries`). \
This library is modified, to allow display flip options and direct access to buffer. So use version of library that included in this repository.
Source: http://arduino.ru/forum/proekty/khronograf-izmeritel-skorosti-puli-ot-prostogo-k-slozhnomu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
### Low-Power-master
Used to allow deep sleep between screen refreshing. 
Library included in this repo. Just copy it to your libraries folder (`C:\Users\USER\Documents\Arduino\libraries`). \
Source: https://github.com/rocketscream/Low-Power
### DS3231M-1.0.6
Used to communicate with RTC module.
Library included in this repo. Just copy it to your libraries folder (`C:\Users\USER\Documents\Arduino\libraries`). \
Source: https://www.arduino.cc/reference/en/libraries/ds3231m/

## Software > How to build
- Install Arduino IDE.
I used Arduino 1.8.16.
Link: https://www.arduino.cc/en/software ;
- Because Arduino IDE don't have drivers for CH340, you need to install drivers manually.
You can find drivers enywhere over Internet.
I found here: https://drive.google.com/file/d/1BqUo6f5WEd1vqdxt1UWzDh4OgjdQ7Mx1/view ;
- Copy libraries to your Arduino IDE libraries folder (`C:\Users\USER\Documents\Arduino\libraries`);
- Open project and try to build it. If all steps done correctly, project will build successfully.

## Software > How to set language
There is 2 options to select language: `Russian` and `English`.\
If you want use `Russian` language, uncomment `#define LANG_RU` string in `Generic.cpp` file.\
If you want use `English` language, uncomment `#define LANG_EN` string in `Generic.cpp` file.\
Only one string can be active at the time. If you select any language, you have to comment other one.

## Software > How to set watchfaces list
You can include multiple watcfaces in firmware. As much as enough FLASH memory.\
You can configure included wathfaces in file `_DRMWatch2.ino`.\
Update number of included watchfaces, comment or uncomment needed watchfaces, check memory usage.\
If no watchface is included in firmware, firmware will dehave unexpectedly.\
Example:


## Software > How to add your own watchface
Project has several watchfaces included, but you always can create your own watchface and use it.
Here's instruction how to do it:
- Create file like `WatchFaceMy`. Use other watchfaces as reference.
- Create function like this: `void WatchfaceThermo(byte hour, byte minute, byte second, byte day, byte month, int year, byte dayOfWeek, byte animate)`. Use other watchfaces as reference.
- This Function draws watchface. You can draw everything you want calling functions from `Display`.
It have to be a non-blocking function, othervise watch will not work properly.
Last argument `animate` is true when system draws watchface last time. You can add `displayUpdate();` 
to make drawing more fancy. 
Use other watchfaces as reference.
- In file `_DRMWatch2` in `setup()` function add your watchface to array. Use other watchfaces as reference.
- Update `watchfacesCount` if needed.
- Now update your watch firmware and you can select your new watchface and use it!

## Software > How to add your own application
You can modify source and add own application.
Program contains several screens (menus, applications).
Every screen is a separate `mode`. Every mode contains of: `modeSetup()`, `modeLoop()`, `modeFinish()`.
Modes can work independently. Modes divided into different files to ease.
Function of main program `loop()` is routing `modeLoop()` to correct mode according to `_mode` value.
Also `setMode()` function is triggering `modeSetup()` and `modeFinish()` for every mode.
To change mode call: `setMode(MODE_INIT);`.
When adding new mode: 
- Create new file with `modeLoop()`, `modeSetup()`, and `modeFinish()` for your mode.
- Define constant for it in main file, like `#define MODE_MENU_SET_BEEP_SOUND (byte)9`.
- Add to main `loop()` call for your `modeLoop()`.
- Call your `modeSetup()` from `setMode()` when entering your mode.
- Call your `modeFinish()` from `setMode()` when leaving your mode.
- Call `setMode(YOUR_MODE);` when you want to enter your new screen.
- Don't forget to call `goToWatchface()` or `setMode()` to exit your mode if needed.
- When your mode is active, only your mode's `loop()` will be called. 
So mode have all control over device. 
If your mode will be empty, so device will do nothing after activation your mode, 
and you can't even exit to menu or reboot if you don't implemented this.
- If you stuck with your mode, the easiest way to reboot watch is connect it to USB and reflash.

## Software > How to add your own melodies
Because of Arduino have <b>VERY</b> limited space, but I want to store long melodies, I made algorythm to 
compress music as much as possible.\
As source I using Nokia-style composer music, named `RTTTL`.\
I made software to convert `RTTTL` to binary codes, which can be played by synthesizer of 
DRM Watch firmware.\
Melodies stored in form of one byte-one note. Array is contains tempo and notes.\
First 2 bits of note is representing note duration (values 4, 8, 16, 32).\
Last 6 bits represents note number counted from low note of first octave.\
Software can be found in `Windows RTTTL to binary converter\RTTTL Converter\bin\Release\net5.0-windows` folder.
To  run app you need to install framework:
`https://dotnet.microsoft.com/en-us/download/dotnet/thank-you/sdk-5.0.408-windows-x64-installer`


To add your melody to melody list:
- Convert your RTTTL melody to binary array;
- In file `MelodyPlayer.ino` add array and `get...()` function with your melody;
- In file `MelodyPlayer.ino` in function `getMelodyByIndex()` add index for your melody;
- In file `MelodyPlayer.ino` in array `modeMenuMelodiesItems` add name of your melody;
- In file `MelodyPlayer.cpp` in function `getMelodyCount()` update melody count;
- Update firmware on your watch;
- Now your melody will appear in list and can be set as alarm.

Melody player: https://zserge.com/nokia-composer/ (link actual 2023-12)
Melody repository: https://nokia.nigelcoldwell.co.uk/tunes.html (link actual 2022-11)
Melody player (non RTTTL, just for fun): http://outputchannel.com/monophonic-ringtone-synthesizer/ (link actual 2023-12)

Video describing this process you can see here:
https://www.youtube.com/watch?v=Ek3eQStupCs

## Software > Default melodies codes

### Badinerie RTTTL
Tempo = 125
```
8b2 16d3 16b2 8#f2 16b2 16#f2 8d2 16#f2 16d2 4b1 16#f1 16b1 16d2 16b1 16#c2 16b1 16#c2 16b1 16#a1 16#c2 16e2 16#c2 8d2 8b1 8b2 16d3 16b2 8#f2 16b2 16#f2 8d2 16#f2 16d2 4b1 8d2 8d2 8d2 8d2 8b2 8d2 32d2 32#c2 32d2 32#c2 8#c2 8#f2 8#f2 8#f2 8#f2 8d3 8#f2 32#f2 32f2 32#f2 32f2 8f2 16#c2 16#f2 16a2 16#f2 16#g2 16#f2 16#g2 16#f2 16f2 16#g2 16b2 16#g2 16a2 16#g2 16a2 16#g2 16#f2 16a2 16#f2 16f2 16#f2 16b2 16#f2 16f2 16#f2 16#c3 16#f2 16f2 16#f2 16d3 16#f2 16f2 16#f2 16d3 16#c3 16b2 16#c3 16a2 16#g2 16#f2 8a2 8#g2 4#f2
```

### Nokia Tune RTTTL
Tempo = 112
```
16g3 16f3 8a2 8b2 16e3 16d3 8f2 8g2 16d3 16c3 8e2 8g2 4.c3
```

### Mozart 40 RTTTL
Tempo = 240
```
8a2 16#g2 16- 8#g2 8- 8a2 16#g2 16- 8#g2 8- 8a2 16#g2 16- 4#g2 8.e3 4- 16- 8e3 16#d3 16- 8#c3 8- 8#c3 16b2 16- 8a2 8- 16.a2 32- 16#g2 16- 8#f2 8- 8#f2 4- 8- 16.#g2 32- 16.#f2 32- 8#f2 8- 8#g2 16#f2 16- 8#f2 8- 8#g2 16#f2 16- 4#f2 8#d3 4- 8- 8#d3 8#c3 8c3 8- 8c3 8a2 16.#g2 8- 32- 8#g2 8#f2 8e2 8- 8e2 4- 8- 8e3 16#d3 16- 4#d3 4#f3 4c3 4#d3 4#c3 4#g2 4- 16.e3 32- 16#d3 16- 4#d3 4#f3 4c3 4#d3 4#c3 4e3 8#d3 8#c3 8b2 8a2 1#g2 1g2 2#g2 4- 16#g1 16- 16#g1 16- 2#g1 4- 16#g1 16- 16#g1 16- 2#g1 4- 16#g1 16- 16#g1 16- 8#g1 8- 16#g1 16- 16#g1 16- 8#g1 8- 16#g1 16- 16#g1 16- 2#g1
```

### Mario RTTTL
Tempo = 100
```
16e2, 16e2, 32-, 8e2, 16c2, 8e2, 8g2, 8-, 8g1, 8-, 8c2, 16-, 8g1, 16-, 8e1, 16-, 8a1, 8b1, 16#a1, 8a1, 16.g1, 16e2, 16g2, 8a2, 16f2, 8g2, 8e2, 16c2, 16d2, 8b1, 16-, 8c2, 16-, 8g1, 16-, 8e1, 16-, 8a1, 8b1, 16#a1, 8a1, 16.g1, 16e2, 16g2, 8a2, 16f2, 8g2, 8e2, 16c2, 16d2, 8b1, 8-, 16g2, 16#f2, 16f2
```

### Toreador RTTTL
Tempo = 165
```
4c3 8.d3 16c3 4a2 4a2 8a2 16- 16g2 8.a2 16#a2 4a2 4- 4#a2 8.g2 16c3 4a2 4- 4f2 8.d2 16g2 4c2 4- 2g2 8g2 8d3 8c3 8#a2 16.a2 32- 8g2 8a2 8#a2 4a2 4- 4e2 4a2 4a2 8#g2 8b2 1e3 8- 32d3 16e3 32d3 8#c3 8d3 8g2 8a2 4#a2 8- 32a2 16#a2 32a2 8f2 8d3 4.c3 4- 32f2 16g2 32f2 8c2 8#a2 8a2 8- 8g2 8- 8f2 2-
```

### Groovy Blue RTTTL
Tempo = 125
```
16f3 1- 16c3 16#d3 16c3 16#d3  16f3 1- 16c3 16#d3 16c3 16#d3 8f3 16f2 8- 16f2 8- 16f2 8- 16f2 8- 16f2 8- 16f2 8- 16c3 16#d3 16c3 16#d3 8f3 16f3 8- 16f3 8- 16f3 8- 16f3 8- 16f3 8- 16f3 8- 16c3 16#d3 16c3 16#d3 8f3 16f3 8#g3 16f3 8#a3 16f3 8- 16f3 8#g3 16f3 16#a3  16- 16f3 8- 16c3 16#d3 16c3 16#d3 8f3 16f3 8#g3 16f3 8#a3 16f3 8- 16f3 8#g3 16f3 16#a3 16- 16f3 8- 16c3 16#d3 16c3 16#d3 8f3 16f3 8#g3 16f3 8b3 16f3 8#a3 16f3 8a3 16f3 8#g3 16f3 8g3 4- 16c3 16#d3 16c3 16#d3 8f3
```

### Entertainer RTTTL
Tempo = 140
```
8d2 8#d2 8e2 4c3 8e2 4c3 8e2 2c3 8c3 8d3 8#d3 8e3 8c3 8d3 4e3 8b2 4d3 2c3 4- 8d2 8#d2 8e2 4c3 8e2 4c3 8e2 2c3 8- 8a2 8g2 8#f2 8a2 8c3 4e3 8d3 8c3 8a2 2d3
```

### Was wollen wir trinken  RTTTL
Tempo = 115
Thanks to @gromozdow98 for writing song into code.
```
8a1 8a1 16g1 16#f1 4g1 4e1 8e1 8a1 8a1 8g1 8#f1 8a1 8a1 16g1 16f1 4g1 4e1 8#f1 8d1 4e1 8-

8a2 8a2 16g2 16#f2 4g2 4e2 8e2 8a2 8a2 8g2 8#f2 8a2 8a2 16g2 16f2 4g2 4e2 8#f2 8d2 4e2 8-

8e2 8g2 8a2 4b2 4b2 8c3 8a2 2b2 8-

8a2 8a2 16g2 16#f2 4g2 4e2 8e2 8a2 8a2 8g2 8#f2 8a2 8a2 16g2 16f2 4g2 4e2 8#f2 8d2 2e2
```

# Project history
A long time ago...
## Project history > 2016, First steps
Back in 2016 me and my friend was playing with arduino and Nokia 5110 LCD.
Then idea of DRM Watch was born. Why "DRM"? It's first letters from my and my friend's nicknames:)
We've assembled one DIY working prototype and stopped development. \
Here's some prorotype photos of these days: 
<p align="center">
  
   
</p>

## Project history > 2021, Development continued
Later, in 2021 for some reason project continued. 
LCD was changed to Nokia 1280 LCD, because it is easier to get and has more reliable connection. 
Here's some prototypes:
<p align="center">

 

 
 
</p>

## Project history > 2022, Closer to complete device
In 2022 I had device with 3d printed case and used it as my daily watch.
<p align="center">
 
 

 
 

</p>

## Project history > Funny fails
Not every step is successful, here's some videos with funny fails:
<p align="center"> https://youtu.be/Ur8o4e1e8V8 </p>
<p align="center"> https://youtu.be/18OF_WzMhGE </p>

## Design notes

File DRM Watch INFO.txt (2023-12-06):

Источники:
https://www.youtube.com/watch?v=t6KwVkY8EA8
https://github.com/igorok107/PCF8814
https://digitalchip.ru/podklyuchenie-displeya-ot-nokia-1100-chast-1/
https://forum.cxem.net/index.php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
https://github.com/kashapovd/PCF8814-Nokia-1100-LCD-library

Информация по энергопотреблению:
5В на входе, дисплей подключен, RTC подключен, TC4056 подключен: 1.76 mA
5В на входе, дисплей подключен, RTC подключен, TC4056 подключен, вечный сон без инициализации: 1.00 mA
5В на входе, дисплей отключен, RTC подключен, TC4056 подключен: 1.69 mA
5В на входе, дисплей отключен с делителем, RTC подключен, TC4056 подключен: 1.06 mA
5В на входе, дисплей подключен без делителея, RTC подключен, TC4056 подключен: 1.64 mA
5В на входе, дисплей подключен без делителея, RTC подключен, TC4056 подключен, после выхода из меню и тушения подветки: 0.71 mA
5В на входе, дисплей подключен, RTC отключен, TC4056 подключен: 1.66 mA
5В на входе, дисплей подключен, RTC подключен, TC4056 отключен: 1.76 mA
5В на входе, дисплей подключен, RTC подключен, Схема защиты: 1.96 mA
С исправленным выводом UART:
4.1в, Arduino со сне: 0.59 мА
4.1в, Без RTC: 0.48 мА
Подсчитанное потребление:
дисплей: 0.070 мА
RTC: 0.100 mA
TC4056: 0.000 мА
Схема защиты АКБ: -0.020 мА
Делитель напряжения дисплея: 0.630 мА

Корпус: Толщина матрицы дисплея: 2.1мм
Толзина рамки 0.36мм

Параметры платы:
Дорожка обычная 0.2
Дорожка силовая 0.3 (просто чтобы было видно)
Дырка 0.3
Металлизация вокруг дырки 0.5

Привести к:
Дырка 0.4

add melody video:
How to add melody to DRM Watch v2 firmware 
DRM Watch repository: https://github.com/drfailov/DRM_Watch_v2
Melody player: https://zserge.com/nokia-composer/ (link actual 2022-11)
Melody repository: https://nokia.nigelcoldwell.co.uk/tunes.html (link actual 2022-11)

Timecodes:
0:00 Intro
0:25 Check if sketch compiling
1:25 Find melody on Internet
2:00 Check if melody correct with player
2:37 Convert melody to binary format
3:35 Add melody code to MediaPlayer.ino
4:05 Add getMelody function for new melody
4:42 Add melody to getMelodiByIndex() function
5:15 Add name of melody to modeMenuMelodiesItems array
6:01 Edit eepromMelodyCount in myEEPROM.cpp
6:40 Compile and upload to DRM Watch
7:49 Check if melody added successfully

Плеер мелодий:
https://zserge.com/nokia-composer/
Ukraine athem:
4e2 8- 8e2 8e2 8d2 8e2 8f2 4g2 8- 8f2 4e2 4d2 4c2 4e2 4b1 4e2 8a1 8#g1 8a1 8b1 4c2 4d2 4e2 8- 8e2 8e2 8d2 8e2 8f2 4g2 8- 8f2 4e2 4d2 4c2 4a1 4e2 4#g1 4a1 4e1 4a1

Eiffel 65: Blue v1 (Tempo=140)	
  4a1 4#a1 8g1 8#a1 8c2 8f1 8a1 4#a1 8g1 8#a1 8d2 4#d2 8d2 8c2 4#a1 8g1 8#a1 8c2 8f1 8a1 4#a1 8g1 8#a1 8d2 4#d2 8d2 8c2 4#a1 8g1 8#a1 8c2 8f1 8a1 4#a1 8g1 8#a1 8d2 4#d2 8d2 8c2 4#a1 8g1 8#a1 8a1 8f1 8f1 2g1
  
Entertainer(Tempo=140)	
  8d2 8#d2 8e2 4c3 8e2 4c3 8e2 2c3 8c3 8d3 8#d3 8e3 8c3 8d3 4e3 8b2 4d3 2c3 4- 8d2 8#d2 8e2 4c3 8e2 4c3 8e2 2c3 8- 8a2 8g2 8#f2 8a2 8c3 4e3 8d3 8c3 8a2 2d3

Harry Potter - Movie Theme(Tempo=125)	
  8b1 8.e2 16g2 8#f2 4e2 8b2 4.a2 4.#f2 8.e2 16g2 8#f2 4d2 8f2 2b1 8- 8b1 8.e2 16g2 8#f2 4e2 8b2 4d3 8#c3 4c3 8#g2 8.c3 16b2 8#a2 4#f2 8g2 2e2 8- 8g2 4b2 8g2 4b2 8g2 4c3 8b2 4#a2 8#f2 8.g2 16b2 8#a2 4#a1

Imperial(Tempo=112)	
  4a1 4a1 4a1 4f1 16c2 4a1 4f1 16c2 2a1 4e2 4e2 4e2 4f2 16c2 4#g1 4f1 16c2 2a1 4a2 4a1 16a1 4a2 4#g2 16g2 16#f2 16f2 4#f2 8#a1 4#d2 4d2 16#c2 16c2 16b1 4c2 8f1 4#g1 4f1 16#g1 4c2 4a1 16c2 2e2 4a2 4a1 16a1 4a2 4#g2 16g2 16#f2 16f2
  
James Bond v1 (Tempo=80)	
  16#d1 32f1 32f1 16f1 8f1 16#d1 16#d1 16#d1 16#d1 32#f1 32#f1 16#f1 8#f1 16f1 16f1 16f1 16#d1 32f1 32f1 16f1 8f1 16#d1 16#d1 16#d1 16#d1 32#f1 32#f1 16#f1 8#f1 16f1 16e1 16#d1 16#d2 2d2 16#a1 16#g1 2#a1
  
Mission Impossible(Tempo=100)	
  16g2 8- 16g2 8- 16f2 16- 16#f2 16- 16g2 8- 16g2 8- 16#a2 16- 16c3 16- 16g2 8- 16g2 8- 16f2 16- 16#f2 16- 16g2 8- 16g2 8- 16#a2 16- 16c3 16- 16#a2 16g2 2d2 32- 16#a2 16g2 2#c2 32- 16#a2 16g2 2c2 16- 16#a1 16c2
  
Popcorn(Tempo=70)	
  16g2 16f2 16g2 16d2 16#a1 16d2 8g1 16g2 16f2 16g2 16d2 16#a1 16d2 8g1 16g2 16a2 16#a2 32g2 16#a2 32g2 16#a2 16a2 32f2 16a2 32f2 16a2 16g2 16f2 16d2 16f2 8g2

Changelog
2021-10-16 Проведены эксперименты с дисплеями, принято решение шото делать
2021-12-03 7 Часов работы, исправления, написания программы
2021-12-04 Заказаны новые RTC
2021-12-04 Исправлена проблема отображения заряда
2021-12-05 добавленю меню
2021-12-05 Перенемены сновные блоки циферблата
2021-12-06 Текстовая часть меню перенесена в PROGMEM
2021-12-06 Место под вывод даты
2021-12-06 Добавлены мелодии (Стас)
2021-12-07 Вынес меню в отдельный файл
2021-12-07 Добавил отдельное меню настроек
2021-12-07 Добавил отдельное меню мелодий
2021-12-07 Начата работа над меню заданий времени
2021-12-08 Напаян RTC и добавлена его инициализация
2021-12-09 Вывод данных с RTC на циферблат
2021-12-09 добавить задержку к началу мелодии
2021-12-09 Добаавить температуру
2021-12-09 Не мигает подсветка
2021-12-09 Доработано задание времени
2021-12-09 Вывод напряжения на циферблат
2021-12-10 В меню пиктограмы а не текст возле кнопок теперь
2021-12-10 Оптимизация кода дисплея
2021-12-11 Wire.setWireTimeout
2021-12-11 Добавлены комментарии к коду
2021-12-12 Рисование векторами маршрутов, для экономии памяти
2021-12-13 Реализована работа с EEPROM
2021-12-13 Добавлено меню выбора времени сна
2021-12-13 Добавлены прерывания, задержка на реакцию кнопок уменьшена
2021-12-13 Исправлены глюки со сном
2021-12-13 Время подстветки экрана исправлено
2021-12-13 Вывод красивых сообщений
2021-12-13 Добавлены реализации функций вывода текста с макросов F()
2021-12-13 Исправлено мерцание после выбора пункта в настройках
2021-12-13 Значительная оптимизация оперативной памяти
2021-12-13 Индикатор батаеи
2021-12-13 индикация процесса зарядки
2021-12-13 энергосберегающий режим
2021-12-13 Єкран About
2021-12-14 Исправлено положение пункта меню выбора времени сна
2021-12-14 Обновил лимиты напряжения
2021-12-14 Исправлена реакция кнопок если держать их дольше 0.0001сек
2021-12-14 Выбор звука кнопок
2021-12-14 Начата разработка конвертера мелодий в код для Arduino
2021-12-15 Конвертер уже парсит меложии и умеет считать частоты
2021-12-15 Начато формирование файла с прикольными мелодиями
2021-12-15 Добавлены мелодии в несжатом виде
2021-12-16 Конвертер уже парсит генерирует сырой код и бинарщину
2021-12-16 Конвертер уже красиво работает
2021-12-16 Конвертер, добавил кнопки очистки и копирования
2021-12-16 Ардуинка научилась воспроизводить мелодии в сжатом виде!!
2021-12-16 Добавил в код много мелодий
2021-12-18 0.15 Оптимизирован код в вопросе энергопотребнения. Стало меньше в 3 раза.
2021-12-18 0.15 Исправлен выход из меню настроек звука и сна.
2021-12-18 0.15 Подвинут предел энергосбережения, чтобы он включался раньше
2021-12-18 0.15 Переинициализация дисплея при смене меню
2021-12-18 0.15 Добавлена версия
2021-12-18 0.15 На экран About добавлена задержка
2021-12-18 0.15 Исправлено: подсветка в режиме энергосбережения работает очень долго
2021-12-19 0.16 пин10 теперь управляет питанием дисплея
2021-12-19 0.16 Перезагрузка устройства теперь перезагружает дисплей снимая с него питание
2021-12-19 0.16 двоеточие секунд сделать мелким
2021-12-20 0.17 Начата реализация беззвучного режима
2021-12-20 0.17 Меню приложений
2021-12-20 0.17 Встроены костыли для поддержки русского
2021-12-20 0.17 Зажатие кнопок
2021-12-20 0.17 Беззвучный режим иконка
2021-12-20 0.17 Оптимизация рисования иконок в меню
2021-12-20 0.17 Оптимизировано меню настроек
2021-12-20 0.17 Выход из меню дебаг и эбаут сразу на вотчфейс
2021-12-21 0.18 Начата реализация секундомера
2021-12-21 0.18 Начат процесс перевода программы на русский
2021-12-21 0.18 Теперь программа после захода в настройки всегда виснет
2021-12-22 0.19 Разрозненные текстовые буферы объединены в общий
2021-12-22 0.19 Оптимизация вывода данных на экран в вопросе памяти
2021-12-22 0.19 Перевод всех экранных меню на русский
2021-12-22 0.19 На данный момент внеплановые перезагрузки исправлены и тесты были пройдены успешно
2021-12-22 0.19 Дополнена функиональность секундомера
2021-12-23 0.20 Дополнена функиональность секундомера
2021-12-23 0.20 Возможность остановить воспроизведение мелодии
2021-12-23 0.20 Экран воспроизведения меложии
2021-12-23 0.20 Кнопка вверх - пропуск анимации для вектора
2021-12-23 0.20 Кнопка вверх - пропуск анимации для сообщения
2021-12-23 0.20 Переписан механизм работы подсветки на циферблате
2021-12-23 0.20 Исправлено: если выбрать звук кнопок "тон" то на русском не отображалось подтверждение
2021-12-23 0.20 Теперь если зайти в меню "звук кнопок", сразу выделяется пункт, который активен сейчас.
2021-12-23 0.20 Теперь если зайти в меню "беззвучный", сразу выделяется пункт, который активен сейчас.
2021-12-23 0.20 Теперь если зайти в меню "время сна", сразу выделяется пункт, который активен сейчас.
2021-12-24 0.21 С экрана воспроизведения убрана шкала, т.к. из-за неё ломался звук
2021-12-24 0.21 "задать время" перевод
2021-12-24 0.21 Начата реализация будильника (сейчас заведён на 8 утра)
2021-12-28 0.22 Реализация функций хранения в EEPROM данных про заведённый будильник
2021-12-28 0.22 Рисование иконки будильника
2021-12-28 0.22 Экран настройки будильника теперь настраивает будильник\
2021-12-28 0.22 Исправлено: нельзя війти з меню приложения
2021-12-29 0.23 Исправлено: при смене настроек будильника скорее всего будет срабатывать будильник
2021-12-29 0.23 Исправлено: при смене времени скорее всего будет срабатывать будильник
2021-12-29 0.23 Исправлено: дефолтная мелодия указывает в пустоту
2021-12-29 0.23 Исправлено: Иконка Play
2021-12-29 0.23 Реализовано: Хард речет
2021-12-29 0.23 Начата реализация сменных циферблатов
2021-12-29 0.23 Добавлен циферблат 2
2021-12-29 0.23 Глобально переименован ModeWatchFace1 -> ModeWatchFace
2021-12-29 0.23 Глобально переименован ModeDebugScreen1 -> ModeStatus
2021-12-29 0.23 Оптимизация текстов и логов
2021-12-29 0.23 Экран статуса заполнен данными
2021-12-29 0.23 Чистка кода
2021-12-30 0.24 Точечная оптимизация памяти 29446 - 28906
2021-12-30 0.24 Добавлен циферблат 3
2021-12-31 1.00 Добавлен циферблат 4
2022-01-01 1.00 Точечная оптимизация памяти 29504 - 29312
2022-01-01 1.00 Реализовано "зрада"
2022-01-01 1.00 Удалено из меню: "свастон"
2022-01-01 1.00 Добавлен день недели на циферблат 1
2022-01-01 1.00 Добавлен день недели на циферблат 2
2022-01-01 1.00 Добавлен день недели на циферблат 3
2022-01-01 1.00 Добавлен день недели на циферблат 4
2022-01-04 1.01 Переименованы циферблаты
2022-01-04 1.01 Siemens перерисован
2022-01-04 1.01 Исправлено воскресенье
2022-01-04 1.01 украсившена анимация загрузки
2022-01-04 1.01 украсившена анимация о программе
2022-01-04 1.01 Анимация входа на циферблат 3
2022-01-05 1.02 Циферблат 3: Расстановка значков MeltemiOS
2022-01-05 1.02 Циферблат 2: расположение значков динамическое
2022-01-05 1.02 Анимация входа циферблат 1
2022-01-05 1.02 Анимация входа циферблат 2
2022-01-05 1.02 Анимация входа циферблат 4
2022-01-07 1.02 новая иконка беззвучности (by meltemios)
2022-01-07 1.02 Сжата иконка будильника
2022-01-07 1.02 Циферблат 1: расположение значков динамическое
2022-01-07 1.02 Версия программы сдвинута на 1 пиксель на экране загрузки
2022-01-10 1.03 Много комментариев в файле дисплея
2022-01-10 1.03 Обновлена икнока будильника (by meltemios)
2022-01-10 1.03 Исправлено: из меню выбора циферблатов нельзя выйти
2022-01-10 1.03 Переделан циферблат Nomens
2022-01-11 1.04 Динамический набор циферблатов на дефайнах
2022-01-11 1.05 Немного оптимизации памяти: 29940 -> 29930 -> 29940 -> 29900 -> 29834 -> 29770 -> 29698 -> 29632 -> 29610 -> 29446 -> 29416
2022-01-11 1.05 Начата реализация циферблата Nokia
2022-01-12 1.06 Много изменений по архитектуре программы
2022-01-13 1.06 Много изменений по архитектуре программы
2022-01-13 1.06 Начаты классы Generic, Display
2022-01-14 1.06 Много изменений по архитектуре программы
2022-01-14 1.06 Закончены классы Generic, Display. Программа снова билдится.
2022-01-14 1.06 Почему-то попердолились PROGMEM массивы. 
2022-01-16 1.07 Исправлено попердоливание циферблатов DRM Lite, Zubat. DRM Watch пока в анабиозе.
2022-01-16 1.07 Исправлено попердоливание графики
2022-01-16 1.07 Исправлено попердоливание экрана статуса
2022-01-16 1.07 Обновлен год
2022-01-16 1.07 Buttons вынесен в класс
2022-01-16 1.07 Zrada восстановлено
2022-01-16 1.07 Добавлена инициализация генератора случайных чисел при запуске Zrada.
2022-01-16 1.07 вернуть отображению анимации графики отмену по кнопке вверх
2022-01-16 1.07 вернуть отображению анимации сообщения отмену по кнопке вверх
2022-01-18 1.08 Battery вынесен в класс
2022-01-18 1.08 RTC вынесен в класс
2022-01-18 1.08 Buzzer вынесен в класс
2022-01-18 1.08 EEPROM вынесен в класс
2022-01-19 1.08 Константы вынесены в Generic.h
2022-01-19 1.08 год один пиксель
2022-01-20 1.09 Начата реализация полиморфизма в циферблатах
2022-01-20 1.09 drm watch день недели вернуть
2022-01-20 1.09 drm watch перенесено в класс
2022-01-20 1.09 drm Lite перенесено в класс
2022-01-21 1.10 Исправлено: Выбор мелодии там пиздец
2022-01-21 1.10 Экран выбора циферблата отображает список циферблатов из массива
2022-01-21 1.10 Защита от перезагрузок если нет ни одного циферблата
2022-01-21 1.10 Восстановлена работа меню выбора циферблата для работы с классами
2022-01-20 1.10 Nomens перенесено в класс
2022-01-20 1.10 Немного оптимизации
2022-01-20 1.11 Циферблат Zubat перенесено в класс
2022-01-20 1.11 Переход циферблатов как ООП
2022-01-20 1.11 Обновлено начертание 7ки
2022-01-20 1.11 Начата реализация циферблата Xelibri
2022-01-25 1.11 Реализован Xelibri
2022-01-26 1.12 Обновлен формат даты на циферблате Xelibri
2022-01-26 1.12 Подвинул цифры на 1 пиксель
2022-01-26 1.12 Убрал иконки с экрана кселибри
2022-01-27 1.12 Начаты эксперименты с главным меню
2022-01-31 1.12 Продолжаю эксперименты с главным меню
2022-01-31 1.12 Главное меню перерисовано полностью
2022-02-01 1.13 Убрал батарею с Xelibri
2022-02-01 1.13 Начал ломать меню настроек
2022-02-02 1.13 Иконка ребут
2022-02-03 1.13 Иконка вочфейс
2022-02-03 1.13 На меню настройки длбавлен выбор вочфейса
2022-02-04 1.13 Иконка сна
2022-02-04 1.13 На меню настройки длбавлен выбор времени сна
2022-02-04 1.13 Оптимизация set Watchface: 29982 - 29728
2022-02-04 1.13 Оптимизация set Sleep Time: 29728 - 29374
2022-02-04 1.13 На меню настройки длбавлен выбор беззвучного режима
2022-02-04 1.13 Оптимизация set Silent Mode: 29398 - 29220
2022-02-07 1.13 Добавлено в настройки: Иконка звука
2022-02-07 1.13 Добавлено в настройки: Пункт звука
2022-02-07 1.13 Добавлено в настройки: Выбор звука
2022-02-07 1.13 Оптимизация set sound: 29024 - 28734
2022-02-08 1.13 Добавлено в настройки: Иконка времени
2022-02-08 1.13 Отключена инициализация экрана при навигации по меню, из-за чего переход между меню стал быстрее
2022-02-08 1.13 Добавлено в настройки: Пункт времени
2022-02-08 1.13 Добавлено в настройки: Иконка сброса
2022-02-08 1.13 Меню настроек DRM Lite Only: 29160 байт - 28832 байт 
2022-02-09 1.14 Начата реализация переворота дисплея
2022-02-10 1.14 Функция рисующая дисплей наоборот
2022-02-10 1.14 Пункт переворота дисплея
2022-02-11 1.14 Инверсия кнопок на экране циферблата
2022-02-11 1.14 Инверсия кнопок на экране Главного меню
2022-02-11 1.14 Инверсия перерисовка элементов на экране Главного меню
2022-02-11 1.14 Инверсия кнопок на экране настроек
2022-02-11 1.14 Инверсия кнопок на экране приложений
2022-02-11 1.14 Инверсия кнопок на экране мелодий
2022-02-11 1.14 Инверсия кнопок на экране плеера
2022-02-11 1.14 Инверсия кнопок на экране настройка времени
2022-02-11 1.14 Инверсия кнопок на экране секундомер
2022-02-12 1.14 Экран статуса теперь инвариативен для поворота экрана
2022-02-12 1.14 Инверсия перерисовка элементов на экране настроек
2022-02-12 1.14 часы более круглое
2022-02-12 1.14 Иконка переворота
2022-02-12 1.14 Инверсия перерисовка элементов на экране мелодии
2022-02-12 1.14 Инверсия перерисовка элементов на экране приложения
2022-02-12 1.14 Восстановлен автовыход с меню настроек
2022-02-12 1.14 Восстановлен автовыход с главного меню
2022-02-12 1.14 Восстановлен автовыход с меню about
2022-02-12 1.14 Чтобы перезагрузить - зажать кнопку вверх на 5 секунд
2022-02-12 1.14 Инверсия перерисовка элементов на экране настройка времени
2022-02-12 1.14 Инверсия перерисовка элементов на экране секундомер
2022-02-12 1.14 Интервал сна задаётся циферблатом, убран с экрана настроек
2022-02-12 1.14 Исправлено: на экране секундомера иконки не вписываются в квадратики
2022-02-13 1.14 Инверсия перерисовка элементов на экране будильник
2022-02-13 1.14 В меню приложений пункт назад перенесено наверх
2022-02-13 1.14 В меню мелоий пункт назад перенесено наверх
2022-02-13 1.14 Оптимизировано: изменена последовательность чтения уровня заряда, 30048 -> 29934
2022-02-13 1.14 Оптимизировано: экран установки будильника фактически переписан 29934 -> 29894 -> 29776 -> 29762
2022-02-13 1.14 Перерисован секундомер, стало красивше (29818)
2022-02-13 1.14 eeprom get melody index вернуть проверку и убрать с экрана мелодий 
2022-02-13 1.14 Немного оптимизировал экран выбора времени(29736)
2022-02-13 1.14 Опция полного сброса, как тестовая, ликвилирована(29592)
2022-02-13 1.14 Меню настроек полностью перерасставлено на экране(29592)
2022-02-13 1.14 Меню настроек добавлены подписи (29750)
2022-02-13 1.14 Меню главное добавлены подписи (29860)
2022-02-13 1.14 Немного оптимизации этого текста (29832)
2022-02-13 1.15 Удалена зрада (28962)
2022-02-13 1.15 Зрада переписана по другому (29006)
2022-02-15 1.16 Начата реализация циферблата матрица, добавлено 1,2
2022-02-16 1.16 Продолжаю делать циферблат матрица, добавлено 3,4
2022-02-17 1.16 Продолжаю делать циферблат матрица, добавлено 5,6
2022-02-19 1.16 Исправлена опечатка в тексте меню настроек
2022-02-19 1.16 Продолжаю делать циферблат матрица, добавлено 7, 8, 9
2022-02-21 1.16 Продолжаю делать циферблат матрица, Восстановлено 7, 2
2022-02-22 1.16 Продолжаю делать циферблат матрица, восстановлено 3, 6
2022-02-22 1.16 Продолжаю делать циферблат матрица, восстановлено 7
2022-02-22 1.16 Уменьшено время подсветки
2022-02-22 1.16 Упрощена анимация загрузки
2022-02-22 1.16 Размещение главного меню
2022-02-23 1.17 Переразмещено меню настроек
2022-02-23 1.17 в код обработки длительного нажатия добавлен дебоунс
2022-02-23 1.17 Исправлена особенность когда при зажатии кнопки при возврате на циферблат блокировалась отрисовка циферблата
2022-02-23 1.17 Немного подчищен код
2022-02-23 1.17 Возврат к циферблату при зажатии кнопки вверх в меню настроек
2022-02-23 1.17 Возврат к циферблату при зажатии кнопки вверх в меню приложений
2022-02-23 1.17 Возврат к циферблату при зажатии кнопки вверх в меню мелодий
2022-02-24 1.18 Если на экране о программе нажать любую кнопку долго - откроется экран статуса
2022-02-24 1.18 Немного оптимизации
2022-02-24 1.18 Перераспределение пунктов меню на экране списка приложений
2022-02-24 1.19 Исправлено попердоленный секундомер
2022-02-25 1.19 Добавляю функции пиксельний работы с дисплеем
2022-02-25 1.19 Переименование файлов
2022-02-26 1.19 Повішен приоритет подсветки в отрисовке всех циферблатов
2022-02-26 1.19 Реализован циферблат с клеточным автоматом "жизнь"
2022-02-27 1.19 Исправлено: main меню если зажать кнопку то не перерисовывается экран
2022-02-27 1.19 Исправлено: Никак не могу решить проблему с тем что когда выходишь на циферблат и сразу же отрисовывается циферблат, если в это время нажать на кнопку, то она не сработает пока не закончится анимация
2022-02-27 1.19 Исправлено: - обновить билиотеку в папке
2022-02-27 1.19 Исправлено: восстановить анимацию
2022-02-28 1.20 Добавлено: дополнить инфу на циферблате жизнь
2022-02-28 1.20 Добавлено:  пока держишь кнопку вниз, подсветка не тушится
2022-02-28 1.20 Добавлено:  пока держишь кнопку вниз, анимация продолжается
2022-02-28 1.20 Допиливаю документацию
2022-03-01 Обновление документации: List of features
2022-03-01 Обновление документации: Overview of watchfaces with photos
2022-03-02 Обновление документации: Photos of device
2022-03-02 Обновление документации: Schematics
2022-03-02 Обновление документации: 3d model
2022-03-02 Обновление документации: Prototype photos
2022-03-02 Обновление документации: First steps
2022-03-03 Обновление документации: Video demo of usage on YouTube
2022-03-03 Обновление документации: Assembly Video
2022-03-03 Обновление документации: Assembly photos
2022-03-03 Обновление документации: assembly instructions
2022-03-03 Обновление документации: How to set language
2022-03-04 Обновление документации: How to add your own melodies
2022-03-04 Обновление документации: Text formatting
2022-03-04 Обновление документации: Stopwatch application
2022-03-04 Обновление документации: Application list screen
2022-03-04 Обновление документации: Main menu screen
2022-03-04 Обновление документации: Watchface screen
2022-03-04 Обновление документации: Init screen
2022-03-04 Обновление документации: How to add your own watchface
2022-03-04 Обновление документации: Alarm
2022-03-04 Обновление документации: Troubleshooting
2022-03-04 Обновление документации: Overview of settings with description
2022-03-05 Обновление документации: About screen
2022-03-05 Обновление документации: debug screen
2022-03-05 Обновление документации: How to build
2022-03-05 Обновление документации: How to add your own application
2022-03-06 1.21 Новая индикация разряженного аккумулятора
2022-03-06 1.21 Изменены пороги уровней заряда
2022-03-06 1.21 логика работы всех циферблатов: первые 30 секунд циферблат обновляется непрерывно, потом переходит на обновления раз в 8 секунд.
2022-03-06 1.21 Соответствующие обновления в документации
2022-03-06 1.21 В связи упрощением логики сна, размер прогаммы уменьшен.
2022-03-06 1.21 если батарея разряжена, не активировать подсветку
2022-03-06 1.21 Исключена ситуация когда индикация низкого заряда накладывается на индикацию зарядки
2022-03-16 1.22 Добавлен Циферблат Calibri
2022-03-16 1.23 Добавлен Циферблат Thermo
2022-03-16 1.24 центровка на єкране термометра
2022-03-16 1.24 секундомер - долгое нажатие сброс
2022-03-16 1.24 уменьшено время долгого нажатия
2022-03-16 1.24 переделано управление секундомером
2022-03-24 1.25 Добавлен гимн Украины
2022-04-02 1.26 Подстровка параметров прошивки
2022-08-09 1.27 Добавлен отдельный экран жизнь
2022-08-09 1.27 На экран воспроизведения мелодии добавлены время и заряд
2022-08-09 1.27 На экране воспроизведения мелодии появилась опция зациклить воспроизведение
2022-08-09 1.27 Дополнения в документации
2022-08-09 1.27 Световые эффекты при воспроизведении мелодий
2022-08-09 1.27 переработы звуки кнопок
2022-08-16 1.28 Оптимизация работы с кнопками (оптимизация памяти, оптимизировано 630 байт памяти!) (30560 - 29930)
2022-08-16 1.28 Зачистка кода от комментариев и рудиментов
2022-08-16 1.28 Оптимизация подстветки дисплея (оптимизация, сэкнономлено 4 байта)
2022-08-16 1.28 Подправлены константы отвечающие за определение уровня заряда для более равномерной индикации
2022-08-16 1.28 На экране задания времени теперь минимальное значение - 2020 год (для простоты и быстроты ввода)
2022-08-16 1.28 Удлинены звуки кнопок (звук выполняет роль дебоунса для кнопок)
2022-08-17 1.29 MEOW
2022-09-24 1.30 Минималичтичный вотчфейс
2022-09-24 1.30 Обновлена документация
2022-09-24 1.30 Начата разработка минималистичной прошивки
2022-10-04 m1.30 Минималистичная прошивка, высвобождено около 7кб памяти для дальнейшей разработки
2022-11-09 Firmware v1.31 Добавлена в прошивку мелодия blue
2022-11-09 Firmware v1.31: Обновления на экране "Справка"
2023-03-12 board V7: перемычка для подключения USB на батку (дебаг)
2023-03-12 board V7: подтяжка к 5В RST
2023-03-12 board V7: дополнены полиготы кнопок
2023-03-12 Firmware v1.32: изменен порядок загрузки таким образом, чтобы мелодия играла до инициализации часов
2023-04-15 Firmware v1.32: Відмова від ООП для оптимізації пам'яті
2023-04-15 Firmware v1.32: Доповнено екран про програму
2023-04-15 Firmware v1.32: переписано спосіб збереження в коді циферблату
2023-04-15 Firmware v1.32: Виправлено помилки в Life, які призводили до рандомної поведінки на гранях дисплея
2023-04-15 Firmware v1.32: допрацьовано структуру меню для економії пам'яті
2023-04-15 Firmware v1.32: Переписано меню налаштувань
2023-04-15 Firmware v1.32: Анімація для меня налаштувань
2023-04-15 Firmware v1.32: почав витаскувати функції іконок в окремий файл
2023-04-15 Firmware v1.32: Повністю новий спосіб обрати циферблат
2023-04-16 Firmware v1.32: Анімація переходу між екранами
2023-04-16 Firmware v1.32: Додано мову: Українська
2023-04-16 Firmware v1.32: Тепер годинник можна відправити в сон
2023-04-16 Firmware v1.32: Переробив всі циферблати
2023-04-16 Firmware v1.32: Переписано код що визначає затиснуту кнопку, стало краще працювати і займати менше місця
2023-04-16 Firmware v1.32: Іконка додана: секундомір, зрада, мелодії, життя
2023-04-16 Firmware v1.32: Інокнка оновлена: Будильник, Назад, Далі, Циферблат, Переворот, Беззвучний, Вибір часу
2023-04-16 Firmware v1.32: Оновлено меню програм
2023-04-16 Firmware v1.32: Оновленю меню мелодій
2023-04-17 Firmware v1.32: виправлено баг що меню не выдкриваэться
2023-04-17 Firmware v1.32: в меню реалізована пагінація
2023-04-17 Firmware v1.32: Виправлено розмір іконок
2023-04-17 Firmware v1.32: Переписано екран встановлення будильника
2023-04-17 Firmware v1.32: Оптимізації по коду
2023-04-17 Firmware v1.32: В статусний рядок додано попередження за 15 секунд про те, що скоро відбудеться автоматичний вихід з меню
2023-11-22 Firmware v1.33: Додано мелодію: was wollen wir trinken
2023-12-06 Firmware v1.34: Оновлено мелодію: was wollen wir trinken

tests:
wfs[i++] = watchfaceCalibri;
wfs[i++] = WatchfaceDrmLite;
wfs[i++] = WatchfaceDrmWatch;
wfs[i++] = WatchfaceNomens;
#define LANG_UA   

1) initial:
Скетч использует 29414 байт (95%)
2) edited button hold:
Скетч использует 29382 байт (95%)
3) Edited some minor 
Скетч использует 29350 байт (95%)
4) Edited battery battery
frame: Скетч использует 29328 байт (95%)
bars:  Скетч использует 29296 байт (95%)
5) Changed type of apps menu and added icons
Скетч использует 29442 байт (95%)
6) Changed type of melidies menu 
Скетч использует 29238 байт (95%)
some additions
Скетч использует 29278 байт (95%)
7) Main menu replaced routine:
Скетч использует 29324 байт (95%) памяти устройства.
8) Apps menu replaced routine:
Скетч использует 29390 байт (95%)
8) Melodies menu replaced routine:
Скетч использует 29298 байт (95%)
9) Settings menu replaced routine:
Скетч использует 29270 байт (95%) памяти устройства.
10) Deleted suddenly appeared LOG
кетч использует 29132 байт (94%) памяти устройства.
11) count WTF index
Скетч использует 29122 байт (94%)
12) Rewrite alarm screen
Скетч использует 29048 байт (94%)
13) Rewrite time screen
Скетч использует 29026 байт (94%)
14) Rewrite displayDraw2DigitNumberWithFrame
Скетч использует 28964 байт (94%) памяти устройства

Планы на будущее:
- циферблат Nokia
- Циферблат ебаный
- циферблат JSON
- Циферблат стрелочный
- циферблат с хуями
- секундомер чтобы работал через RTC
- таймер

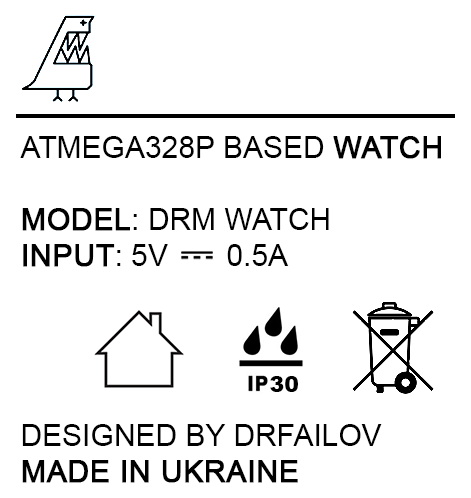
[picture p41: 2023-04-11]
Case/Back Cover Engraving V1.png

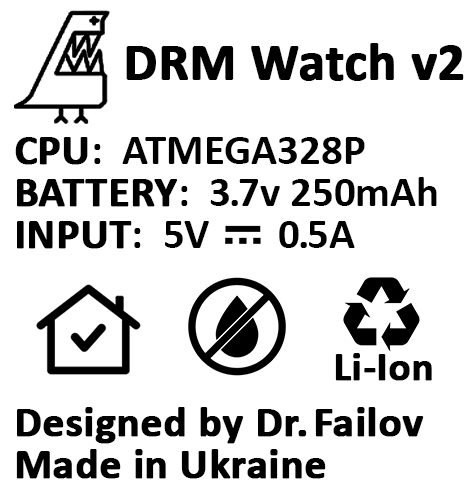
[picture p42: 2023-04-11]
Case/Back Cover Engraving V2.png

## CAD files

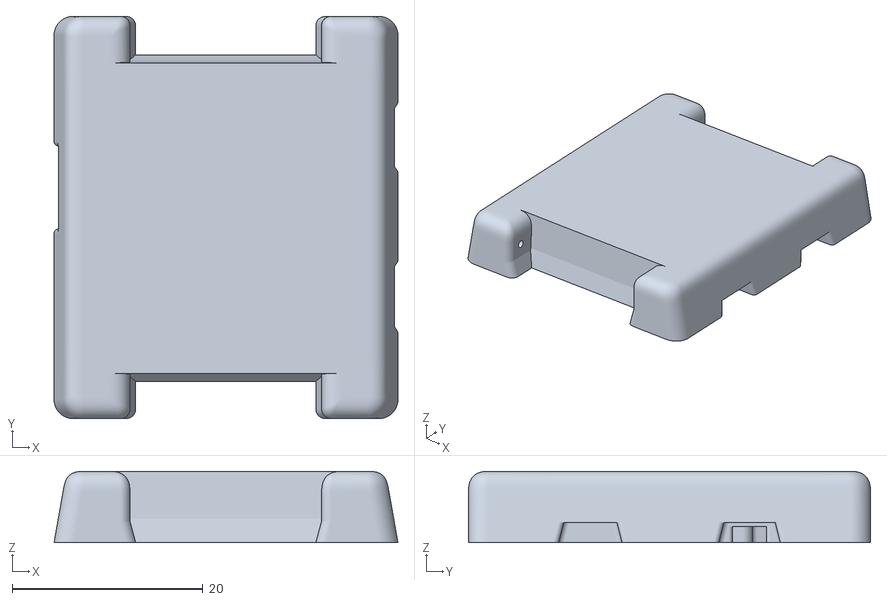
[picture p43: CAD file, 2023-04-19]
Case/Back Case FDM v85.stl
36.1 x 42.2 x 7.50

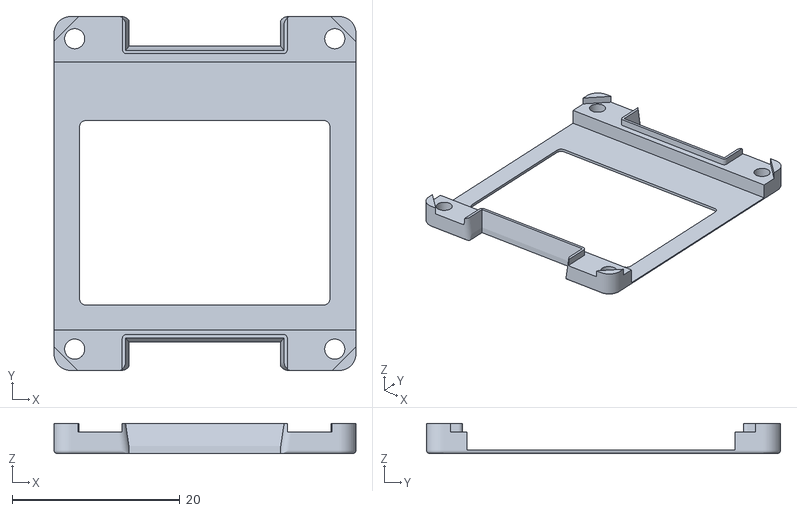
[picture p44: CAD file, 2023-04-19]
Case/Front Case FDM v85.stl
36.0 x 42.2 x 3.60

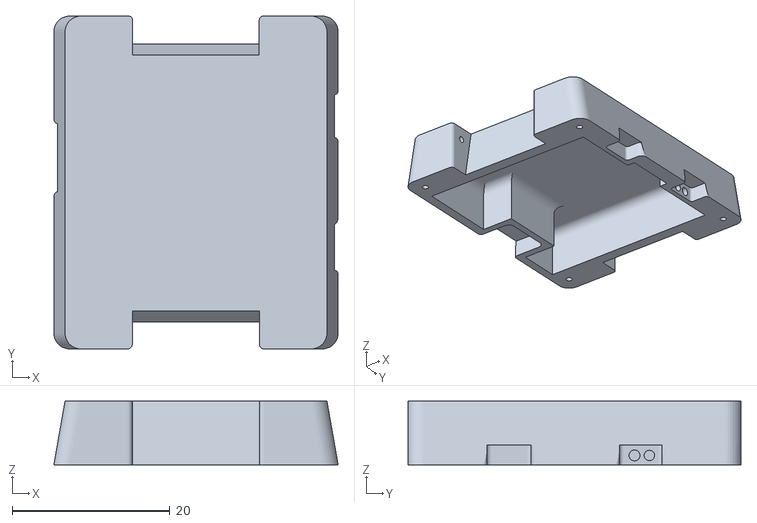
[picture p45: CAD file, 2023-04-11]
Case/2023-04-08 Back-FDM-v60.stl
36.0 x 42.2 x 8.10

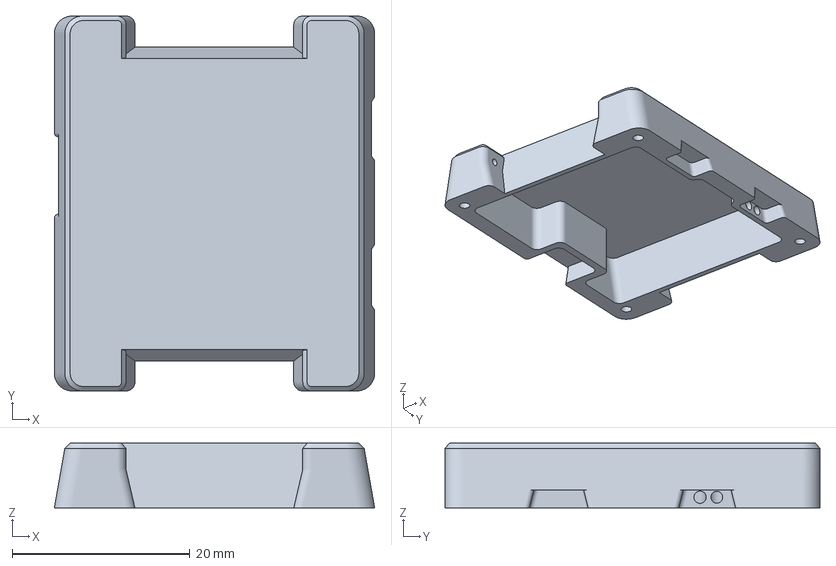
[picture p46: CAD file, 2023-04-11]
Case/Back Case v66.3mf
36.1 x 42.2 x 7.30 mm

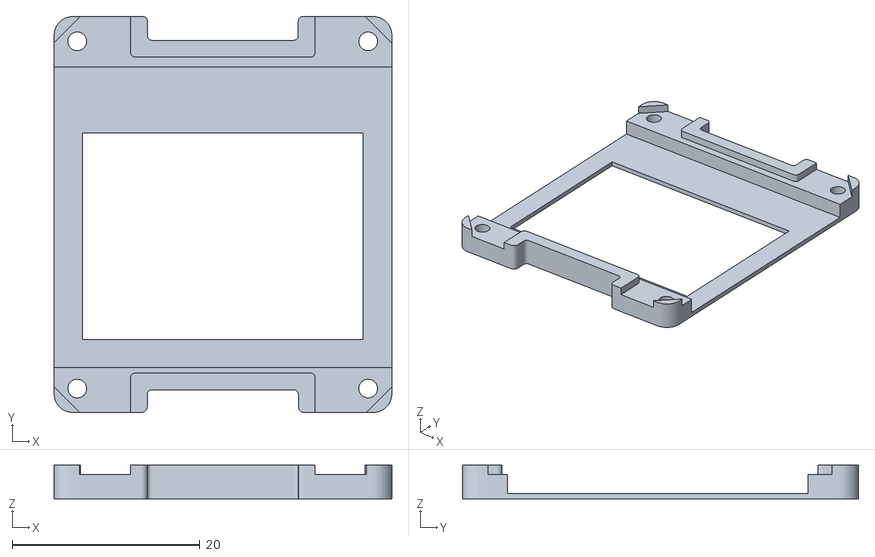
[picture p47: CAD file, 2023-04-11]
Case/2023-04-08 Front-FDM-v57.stl
36.0 x 42.2 x 3.60

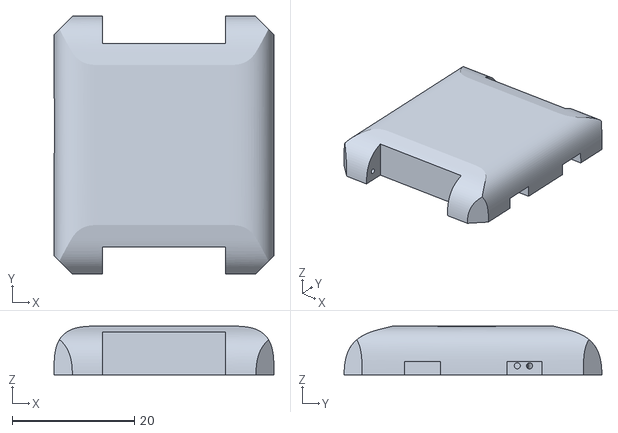
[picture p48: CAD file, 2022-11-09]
Case/2022-10-12 Back v38.stl
35.9 x 42.1 x 8.00

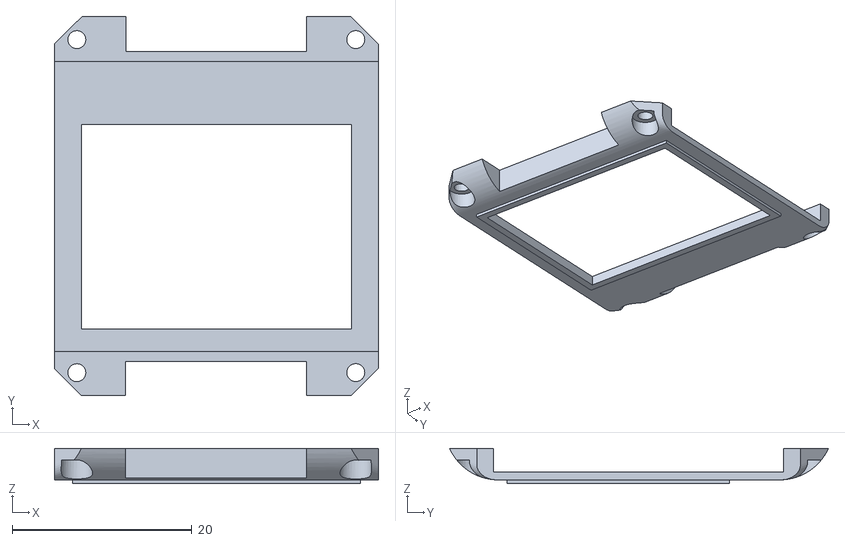
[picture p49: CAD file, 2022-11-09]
Case/2022-10-06 Front v35.stl
36.0 x 42.1 x 3.90

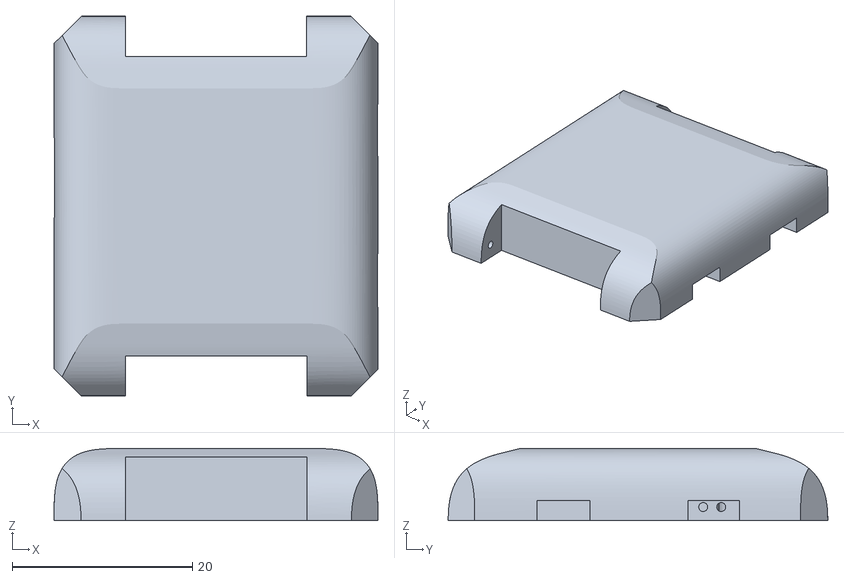
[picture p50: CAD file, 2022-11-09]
Case/2022-10-06 Back v35.stl
35.9 x 42.1 x 8.00

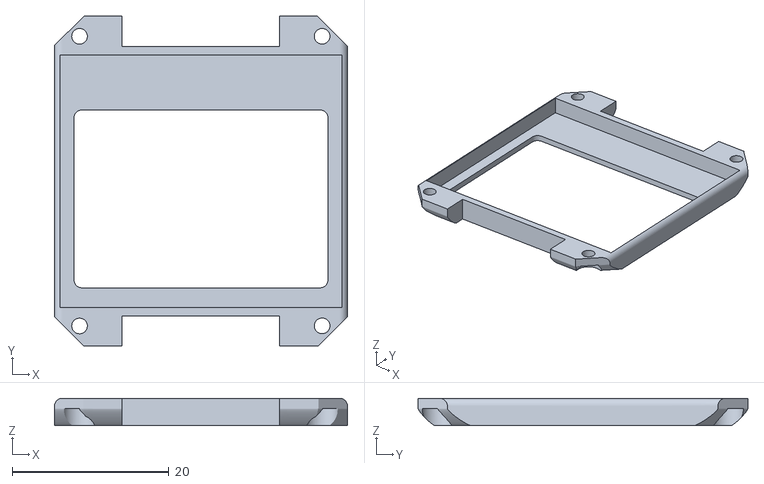
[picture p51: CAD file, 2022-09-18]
Case/2022-09-12 Front v30.stl
37.4 x 42.1 x 3.50

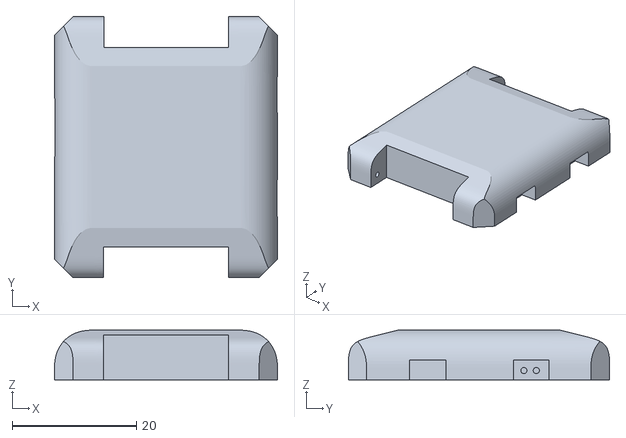
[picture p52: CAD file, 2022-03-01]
Case/2022-03-01 Back v24.stl
35.9 x 42.1 x 8.00

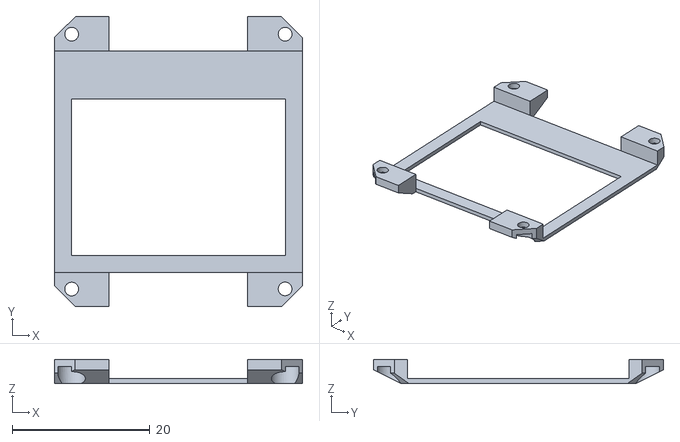
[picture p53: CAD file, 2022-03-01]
Case/2022-03-01 Front No Chamfer v24.stl
36.0 x 42.1 x 3.50

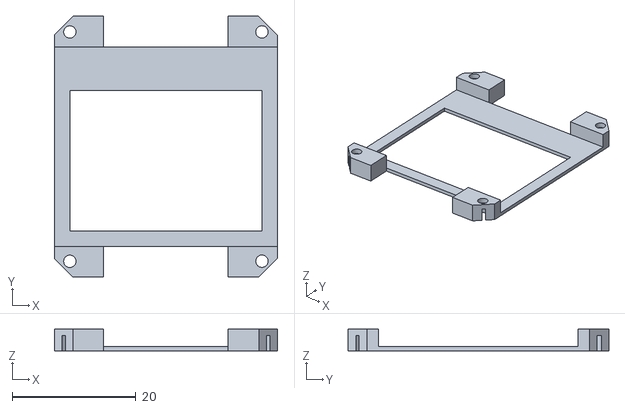
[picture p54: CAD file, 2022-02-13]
Case/2022-02-13 Front No Chamfer v18.stl
36.0 x 42.1 x 3.50

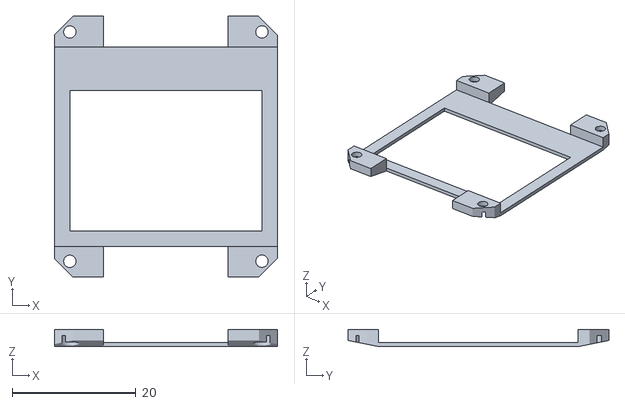
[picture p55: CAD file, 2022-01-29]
Case/2022-01-26 Front With Chamfer v16.stl
36.0 x 42.1 x 2.80

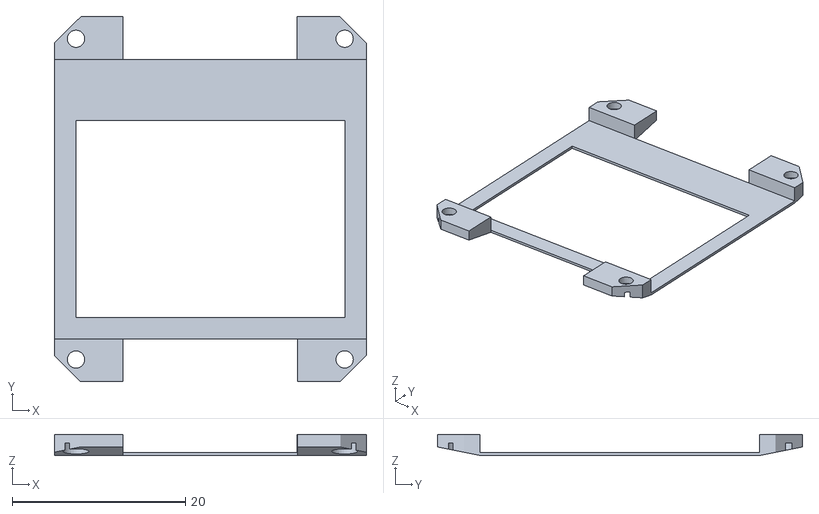
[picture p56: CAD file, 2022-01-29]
Case/2022-01-26 Front With Chamfer v14.stl.stl
36.0 x 42.1 x 2.46

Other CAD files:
Case/2022-09-12 Back v30.stl
Case/2022-02-19 Back v21.3mf
Case/2022-01-26 Front No Chamfer v16.stl
Case/Back Case v8.step
Case/2022-01-22 Back v8.stl.stl
Case/2022-01-26 Front No Chamfer v14.stl
Case/2022-02-19 Back v20.3mf
Case/Back Case FDM v80.stl
Case/Front Case FDM v71.stl

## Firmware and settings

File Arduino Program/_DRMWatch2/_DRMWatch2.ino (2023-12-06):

#include <util/atomic.h>
#include <LowPower.h>

/*Данные, которые требуется по всей программе*/
//Базовые константы
#define version F("v1.34")   //Версию менять здесь
//#define LANG_EN  //Раскомментировать чтобы использовать английский язык меню
//#define LANG_RU   //Раскомментировать чтобы использовать русский язык меню
#define LANG_UA   //Розкоментувати щоб використовувати українську мову в меню
#define LOG   //Закомментировать чтобы отключило логи
#define  AUTO_EXIT_TIMEOUT 180000 //MS  //Время до автоматического выхода с менюшек

//Распиновка
#define pinButtonDown (byte)2 //active high
#define pinButtonUp (byte)3 //active high
#define pinLcdRst (byte)5
#define pinLcdCs (byte)6
#define pinLcdMosi (byte)7
#define pinLcdSck (byte)8   
#define pinLcdPower (byte)10
#define pinUsbVoltage (byte)11  
#define pinBuzzer (byte)12 //passive
#define pinLed (byte)13  //active high
#define pinLcdBacklight (byte)15  //A1, active high
// A4 - RTC SDA
// A5 - RTC SCL

//размер текстового буфера. Чем меньше тем экономнее.
#define BUFFER_SIZE 25
//последнее действие кнопками, нужно для автоматического выхода
long genericMenuLastActionTime = 0;   
//общий на всю программу текстовый буфер чтобы не объявлять каждый раз локальную.
char buffer[BUFFER_SIZE]; 
//Общий на всю программу счётчик для выбора элементов из списка
byte selected = 0;
//используется на экранах с анимацией
bool animate;

//Общий формат вывода данных много где используется
const char* dateFormat = "%02d.%02d.%04d";
const char* timeFormat = "%02d:%02d";



/* Program contains several screens (menus, watchfaces...).
 * Every screen is a separate mode. Every mode contains of: modeSetup(), modeLoop(), modeFinish().
 * Screens can work independently. Modes divided into different files to ease.
 * Function loop() is routing loop() co correct dcreen according to active mode.
 * Also setMode() function is triggering modeSetup() and modeFinish() for every mode.
 * To change mode call: setMode(MODE_INIT);
 * When adding new mode, it needs to be declared: 
 *    - define constant for it,
 *    - loop() call for modeLoop()
 *    - call its setup() from setMode()
 *    - call its finish() from setMode()
*/
//Modes
//Значения констант режимов
#define MODE_INIT (byte)0
#define MODE_WATCHFACE (byte)1
#define MODE_MENU_MAIN (byte)2
#define MODE_STATUS (byte)3
#define MODE_MENU_MELODIES (byte)4
#define MODE_MENU_SETTINGS (byte)5
#define MODE_MENU_SET_TIME (byte)6
#define MODE_ABOUT (byte)8
#define MODE_MENU_APPS (byte)11
#define MODE_STOPWATCH (byte)12
#define MODE_SET_ALARM (byte)13
#define MODE_GAME_OF_LIFE (byte)14
#define MODE_OFF (byte)15
//Переменная в которой хранится текущий режим
byte _mode = -1;

//Набор циферблатов 
typedef void (*WF) (const byte hour, const byte minute, const byte second, const byte day, const byte month, const int year, const byte dayOfWeek, const byte animate);
const byte watchfacesCount = 7;
WF wfs[watchfacesCount];

void setup() {
  byte i=0;
  //Набор циферблатов следует менять именно здесь. 
  //number of WFs here need to less or equal than watchfacesCount, otherwise will crash
  wfs[i++] = watchfaceZubat;
  wfs[i++] = watchfaceCalibri;
  //wfs[i++] = watchfaceXelibri;
  wfs[i++] = WatchfaceDrmLite;
  wfs[i++] = WatchfaceDrmWatch;
  wfs[i++] = WatchfaceLife;
  wfs[i++] = WatchfaceMinimal;
  //wfs[i++] = WatchfaceMatrix;
  //wfs[i++] = WatchfaceThermo;
  //wfs[i++] = WatchfaceNomens;
  
   
#ifdef LOG
  Serial.begin(115200);
  Serial.println(F("DRM Watch V2"));
  Serial.println(version);
  Serial.print(F(__DATE__));
  Serial.print(F(" "));
  Serial.println(F(__TIME__));
#endif  

  setMode(MODE_INIT);
}

void loop() {
  if (_mode == MODE_INIT) modeInitLoop();
  if (_mode == MODE_WATCHFACE) modeWatchFaceLoop(false);
  if (_mode == MODE_MENU_MAIN ) modeMenuMainLoop();
  if (_mode == MODE_STATUS ) modeStatusLoop();
  if (_mode == MODE_MENU_MELODIES ) modeMenuMelodiesLoop();
  if (_mode == MODE_MENU_SETTINGS ) modeMenuSettingsLoop();
  if (_mode == MODE_MENU_SET_TIME ) modeMenuSetTimeLoop();
  if (_mode == MODE_ABOUT ) modeAboutLoop();
  if (_mode == MODE_MENU_APPS ) modeMenuAppsLoop();
  if (_mode == MODE_STOPWATCH ) modeStopwatchLoop();
  if (_mode == MODE_SET_ALARM ) modeSetAlarmLoop();
  if (_mode == MODE_GAME_OF_LIFE ) modeGameOfLifeLoop();
  if (_mode == MODE_OFF ) modeOffLoop();
}

void setMode(int _modeNew) {
  if (_mode == _modeNew)
    return;
#ifdef LOG
  Serial.print(F("Mode "));
  Serial.print(_mode);
  Serial.print(F("->"));
  Serial.println(_modeNew);
  
  Serial.print(F("RAM: "));
  Serial.println(freeRam());
#endif
  //animate transition
  displayTransition();
  //finish old
  if (_mode == MODE_INIT) modeInitFinish();
  if (_mode == MODE_WATCHFACE) modeWatchFaceFinish();
  if (_mode == MODE_STATUS ) modeStatusFinish();
  if (_mode == MODE_ABOUT ) modeAboutFinish();
  if (_mode == MODE_STOPWATCH ) modeStopwatchFinish();
  if (_mode == MODE_GAME_OF_LIFE ) modeGameOfLifeFinish();
  
  //init new
  if (_modeNew == MODE_INIT) modeInitSetup();
  if (_modeNew == MODE_WATCHFACE) modeWatchFaceSetup();
  if (_modeNew == MODE_MENU_MAIN ) modeMenuMainSetup();
  if (_modeNew == MODE_STATUS ) modeStatusSetup();
  if (_modeNew == MODE_MENU_MELODIES ) modeMenuMelodiesSetup();
  if (_modeNew == MODE_MENU_SETTINGS ) modeMenuSettingsSetup();
  if (_modeNew == MODE_MENU_SET_TIME ) modeMenuSetTimeSetup();
  if (_modeNew == MODE_ABOUT ) modeAboutSetup();
  if (_modeNew == MODE_MENU_APPS ) modeMenuAppsSetup();
  if (_modeNew == MODE_STOPWATCH ) modeStopwatchSetup();
  if (_modeNew == MODE_SET_ALARM ) modeSetAlarmSetup();  
  if (_modeNew == MODE_GAME_OF_LIFE ) modeGameOfLifeSetup(); 
  if (_modeNew == MODE_OFF ) modeOffInit();  
  
  
  _mode = _modeNew;
}

//Выплнить всю последовательность действий требуемых для выполнения перезагрузки.
void powerOff(){
  setMode(MODE_OFF);
}

//переключить на режим выбранного в меню вотчфейса из любого места программы
void goToWatchface(){
  setMode(MODE_WATCHFACE);
}

//объём свободной оперативки нужен для отладки
int freeRam () {
  extern int __heap_start, *__brkval;
  int v;
  return (int) &v - (__brkval == 0 ? (int) &__heap_start : (int) __brkval);
}

//обновляем счётчик миллисекунд во время сна чтобы не ломались счётчики
void setMillis(unsigned long ms){
    extern unsigned long timer0_millis;
    ATOMIC_BLOCK (ATOMIC_RESTORESTATE) {
        timer0_millis = ms;
    }
}

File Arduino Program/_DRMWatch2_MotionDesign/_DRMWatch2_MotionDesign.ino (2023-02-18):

#include "lcd1202.h"

//Распиновка
#define pinButtonDown (byte)2 //active high
#define pinButtonUp (byte)3 //active high
#define pinLcdRst (byte)5
#define pinLcdCs (byte)6
#define pinLcdMosi (byte)7
#define pinLcdSck (byte)8   
#define pinLcdPower (byte)10
#define pinUsbVoltage (byte)11  
#define pinBuzzer (byte)12 //passive
#define pinLed (byte)13  //active high
#define pinLcdBacklight (byte)15  //A1, active high
// A4 - RTC SDA
// A5 - RTC SCL


#define LCD_X        96
#define LCD_Y        68
LCD1202 lcd(pinLcdRst, pinLcdCs, pinLcdMosi, pinLcdSck);


void setup() {
  //LCD PWR ON
  pinMode(pinLcdPower, OUTPUT);
  digitalWrite(pinLcdPower, HIGH);
  pinMode(pinLcdBacklight, OUTPUT);
  digitalWrite(pinLcdBacklight, HIGH);
  delay(100);
  lcd.Inicialize();  
}




float tx = 20;
float ty = 40;
float cx = -20;
float cy = 100;
float vx = 0;
float vy = 0;

unsigned long last = 0;


void loop() {  
  float dx = tx-cx;
  float dy = ty-cy;
  float ax = dx*0.3;
  float ay = dy*0.3;
  vx += ax;
  vy += ay;
  cx += vx;
  cy += vy;
  vx *= 0.2;
  vy *= 0.2;
  
  lcd.Clear_LCD();
  lcd.print(/*X*/cx, /*Y*/cy, /*color*/1, /*text*/ "DRM Watch");
  lcd.Update(/*flip*/false);  //true is flip 180, false is no flip
  if(millis()-last > 2000){
    last = millis();
    tx = rand() % 80;
    ty = rand() % 64;
  }
}

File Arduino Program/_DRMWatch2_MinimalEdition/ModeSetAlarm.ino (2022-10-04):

#include "Display.cpp"
#include "Buttons.cpp"
#include "RTC.cpp"
#include "Generic.cpp"
#include "Buzzer.cpp"

/*Screen allows to set time*/

#define MODE_SET_ALARM_SELECTED_BACK 0
#define MODE_SET_ALARM_SELECTED_TOGGLE 1
#define MODE_SET_ALARM_SELECTED_HOUR 2
#define MODE_SET_ALARM_SELECTED_MINUTE 3
#define MODE_SET_ALARM_SELECTED_MELODY 4


void modeSetAlarmSetup(){
  genericMenuSetup();
}

void modeSetAlarmLoop(){
  if (isButtonUpPressed()){ //change value
    Buzzer.beep();
    if(Generic.selected == MODE_SET_ALARM_SELECTED_BACK) {//BACK
      setMode(MODE_MENU_APPS);
      return;
    }
    else if(Generic.selected == MODE_SET_ALARM_SELECTED_TOGGLE) {//ON/OFF
      MyEEPROM.eepromSaveAlertEnabled(!MyEEPROM.eepromReadAlertEnabled());
      resetAlertMetadata();
    }
    else if(Generic.selected == MODE_SET_ALARM_SELECTED_HOUR) {//hours
      MyEEPROM.eepromSaveAlertHour(MyEEPROM.eepromReadAlertHour() + 1);
      resetAlertMetadata();
    }
    else if(Generic.selected == MODE_SET_ALARM_SELECTED_MINUTE) {//Minutes
      MyEEPROM.eepromSaveAlertMinute(MyEEPROM.eepromReadAlertMinute() + 1);
      resetAlertMetadata();
    }
    else if(Generic.selected == MODE_SET_ALARM_SELECTED_MELODY) {//melody
      MyEEPROM.eepromSaveAlertMelodyIndex(MyEEPROM.eepromReadAlertMelodyIndex() + 1);
    }
  }

  if (isButtonDownPressed()){ ////move next
    Buzzer.beep();
    Generic.selected ++;
    if(Generic.selected > 4) Generic.selected = 0;
  }

  
  Display.displayClear();
  byte xOffset = 13;
  if(/*flip*/MyEEPROM.eepromReadFlipScreen())
    xOffset = 0;

  //BACK
  Display.displayDrawIconWithFrame(/*x*/xOffset, /*y*/0, /*additionalWidth*/0, /*drawIcon(x,y,color)*/Display.displayDrawArrowLeft, /*selected*/Generic.selected == MODE_SET_ALARM_SELECTED_BACK);

  //TITLE
  Display.displayDrawText(xOffset+25, 4, 1, F("Alarm"));
  

  //ENABLE \ DISABLE
  Display.displayDrawIconWithFrame(/*x*/xOffset, /*y*/25, /*additionalWidth*/0, /*drawIcon(x,y,color)*/(MyEEPROM.eepromReadAlertEnabled()?Display.displayDrawSilentModeOffIcon:Display.displayDrawSilentModeIcon), /*selected*/Generic.selected == MODE_SET_ALARM_SELECTED_TOGGLE);
  
  
  //hours
  Display.displayDraw2DigitNumberWithFrame(/*x*/xOffset+39, /*y*/25, /*number*/MyEEPROM.eepromReadAlertHour(), /*selected*/Generic.selected == MODE_SET_ALARM_SELECTED_HOUR); 
  //:
  Display.displayDrawText(xOffset+59, 29, 1, ":");
  //minutes
  Display.displayDraw2DigitNumberWithFrame(/*x*/xOffset+64, /*y*/25, /*number*/MyEEPROM.eepromReadAlertMinute(), /*selected*/Generic.selected == MODE_SET_ALARM_SELECTED_MINUTE); 
  
  { //melody
    strlcpy_P(Generic.buffer, getMelodyName(MyEEPROM.eepromReadAlertMelodyIndex()), BUFFER_SIZE);
    if(Generic.selected == MODE_SET_ALARM_SELECTED_MELODY){
      Display.displayFillRect(/*x*/xOffset+0, /*y*/44, /*w*/83, /*h*/15, /*c*/1);
      Display.displayDrawText(xOffset+4, 48, 0, Generic.buffer);
    }
    else{
      Display.displayDrawRect(/*x*/xOffset+0, /*y*/44, /*w*/83, /*h*/15, /*c*/1);
      Display.displayDrawText(xOffset+4, 48, 1, Generic.buffer);
    }
  }

  
  
  
  

  //LEGEND
  Display.drawLegend();
  
  
  Display.displayUpdate();
}

//fix alarm, предотвращение включения будильника сразу в момент установки
void resetAlertMetadata(){
  byte hour = RTC.rtcGetHours();
  byte minute = RTC.rtcGetMinutes();
  byte day = RTC.rtcGetDay();
  if((hour == MyEEPROM.eepromReadAlertHour() && minute >= MyEEPROM.eepromReadAlertMinute()) || (hour > MyEEPROM.eepromReadAlertHour()))
    MyEEPROM.eepromSaveAlertLastDayRun(day);
  else
    MyEEPROM.eepromSaveAlertLastDayRun(0);
}

void modeSetAlarmFinish(){
}

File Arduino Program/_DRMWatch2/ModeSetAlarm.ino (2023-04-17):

#define MODE_SET_ALARM_SELECTED_BACK 0
#define MODE_SET_ALARM_SELECTED_TOGGLE 1
#define MODE_SET_ALARM_SELECTED_HOUR 2
#define MODE_SET_ALARM_SELECTED_MINUTE 3
#define MODE_SET_ALARM_SELECTED_MELODY 4

void modeSetAlarmSetup(){
  genericMenuSetup();
}

void modeSetAlarmLoop(){//y:13, 32, 
  if(genericMenuRoutine(modeSetAlarmSelected, 5))return;  
  
  const byte xOffset = eepromReadFlipScreen()? 0 : 13;
  byte y=13;
  displayDrawIconWithFrame(/*index*/MODE_SET_ALARM_SELECTED_BACK, /*x*/xOffset, /*y*/y, /*icon*/displayDrawBackIcon);   //BACK
  y+=19;
  displayDrawIconWithFrame(/*index*/MODE_SET_ALARM_SELECTED_TOGGLE, /*x*/xOffset, /*y*/y, /*icon*/(eepromReadAlertEnabled()?displayDrawSilentModeOffIcon:displayDrawSilentModeIcon)); //ENABLE \ DISABLE
  displayDraw2DigitNumberWithFrame(MODE_SET_ALARM_SELECTED_HOUR, /*x*/xOffset+39, /*y*/y, /*number*/eepromReadAlertHour());  //hours
  displayDrawText(xOffset+59, y+4, 1, ":"); //:
  displayDraw2DigitNumberWithFrame(MODE_SET_ALARM_SELECTED_MINUTE, /*x*/xOffset+64, /*y*/y, /*number*/eepromReadAlertMinute());  //minutes
  y+=19;
  { //melody
    strlcpy_P(buffer, getMelodyName(eepromReadAlertMelodyIndex()), BUFFER_SIZE);
    (selected == MODE_SET_ALARM_SELECTED_MELODY?displayFillRect:displayDrawRect)(/*x*/xOffset+0, /*y*/y, /*w*/83, /*h*/15, /*c*/1);
    displayDrawText(xOffset+4, y+4, selected != MODE_SET_ALARM_SELECTED_MELODY, buffer);
  }  
  displayUpdate();
}

void modeSetAlarmSelected(){
  if(selected == MODE_SET_ALARM_SELECTED_BACK) {//BACK
      setMode(MODE_MENU_APPS);
      return;
    }
    else if(selected == MODE_SET_ALARM_SELECTED_TOGGLE) {//ON/OFF
      eepromSaveAlertEnabled(!eepromReadAlertEnabled());
      resetAlertMetadata();
    }
    else if(selected == MODE_SET_ALARM_SELECTED_HOUR) {//hours
      eepromSaveAlertHour(eepromReadAlertHour() + 1);
      resetAlertMetadata();
    }
    else if(selected == MODE_SET_ALARM_SELECTED_MINUTE) {//Minutes
      eepromSaveAlertMinute(eepromReadAlertMinute() + 1);
      resetAlertMetadata();
    }
    else if(selected == MODE_SET_ALARM_SELECTED_MELODY) {//melody
      eepromSaveAlertMelodyIndex(eepromReadAlertMelodyIndex() + 1);
    }
}


//fix alarm, предотвращение включения будильника сразу в момент установки
void resetAlertMetadata(){
  byte hour = rtcGetHours();
  byte minute = rtcGetMinutes();
  byte day = rtcGetDay();
  if((hour == eepromReadAlertHour() && minute >= eepromReadAlertMinute()) || (hour > eepromReadAlertHour()))
    eepromSaveAlertLastDayRun(day);
  else
    eepromSaveAlertLastDayRun(0);
}

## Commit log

2021-12-09 2021-12-09 Вывод данных с RTC на циферблат 2021-12-09 добавить задержку к началу мелодии 2021-12-09 Добаавить температуру
2021-12-09 2021-12-09 Вывод данных с RTC на циферблат 2021-12-09 добавить задержку к началу мелодии 2021-12-09 Добаавить температуру 2021-12-09 Не мигает подсветка 2021-12-09 Доработано задание времени 2021-12-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
2021-12-11 В меню пиктограмы а не текст возле кнопок теперь ,Оптимизация кода дисплея
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2021-12-13 2021-12-13 Реализована работа с EEPROM 2021-12-13 Добавлено меню выбора времени сна 2021-12-13 Добавлены прерывания, задержка на реакцию кнопок уменьшена
2021-12-13 2021-12-13 Время подстветки экрана исправлено 2021-12-13 Вывод красивых сообщений
    [Display.ino, ModeInit.ino, ModeWatchFace1.ino]
2021-12-13 2021-12-13 Реализована работа с EEPROM 2021-12-13 Добавлено меню выбора времени сна 2021-12-13 Добавлены прерывания, задержка на реакцию кнопок уменьшена 2021-12-13 Исправлены глюки со сном 2021-12-1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
    [Battery.ino, Display.ino, GenericMenu.ino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]
2021-12-14 2021-12-14 Исправлено положение пункта меню выбора времени сна 2021-12-14 Обновил лимиты напряжения 2021-12-14 Исправлена реакция кнопок если держать их дольше 0.0001сек 2021-12-14 Выбор звука кнопок
    [Battery.ino, Buzzer.ino, Display.ino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]
2021-12-15 2021-12-15 Конвертер уже парсит меложии и умеет считать частоты 2021-12-15 Начато формирование файла с прикольными мелодиями 2021-12-15 Добавлены мелодии в несжатом виде
2021-12-16 2021-12-16 Конвертер уже парсит генерирует сырой код и бинарщину 2021-12-16 Конвертер уже красиво работает 2021-12-16 Конвертер, добавил кнопки очистки и копирования
2021-12-16 021-12-16 Конвертер уже парсит генерирует сырой код и бинарщину 2021-12-16 Конвертер уже красиво работает 2021-12-16 Конвертер, добавил кнопки очистки и копирования 2021-12-16 Ардуинка научилась восп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
2021-12-18 2021-12-18 0.15 Оптимизирован код в вопросе энергопотребнения. Стало меньше в 3 раза. 2021-12-18 0.15 Исправлен выход из меню настроек звука и сна. 2021-12-18 0.15 Подвинут предел энергосбережения, ч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
    [Battery.ino, Buzzer.ino, Display.ino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]
2021-12-19 2021-12-19 0.16 пин10 теперь управляет питанием дисплея 2021-12-19 0.16 Перезагрузка устройства теперь перезагружает дисплей снимая с него питание 2021-12-19 0.16 двоеточие секунд сделать мелким
2021-12-20 2021-12-20 0.17 Начата реализация беззвучного режима 2021-12-20 0.17 Меню приложений 2021-12-20 0.17 Встроены костыли для поддержки русского 2021-12-20 0.17 Зажатие кнопок 2021-12-20 0.17 Беззвучный 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
2021-12-21 2021-12-21 0.18 Начата реализация секундомера 2021-12-21 0.18 Начат процесс перевода программы на русский 2021-12-21 0.18 Теперь программа после захода в настройки всегда виснет
2021-12-22 2021-12-21 0.19 Разрозненные текстовые буферы объединены в общий 2021-12-21 0.19 Оптимизация вывода данных на экран в вопросе памяти 2021-12-21 0.19 Перевод всех экранных меню на русский 2021-12-21 0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
    [Display.ino, GenericMenu.ino, ModeMenuApps.ino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]
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2021-12-23 2021-12-21 0.20 Дополнена функиональность секундомера 2021-12-21 0.20 Возможность остановить воспроизведение мелодии 2021-12-21 0.20 Экран воспроизведения меложии 2021-12-21 0.20 Кнопка вверх - пропу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
    [1ModeWatchFace.ino, Display.ino, MelodyPlayer.ino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]
2021-12-24 2021-12-24 0.21 С экрана воспроизведения убрана шкала, т.к. из-за неё ломался звук 2021-12-24 0.21 "задать время" перевод 2021-12-24 0.21 Начата реализация будильника
2021-12-24 2021-12-24 0.21 С экрана воспроизведения убрана шкала, т.к. из-за неё ломался звук 2021-12-24 0.21 "задать время" перевод 2021-12-24 0.21 Начата реализация будильника (сейчас заведён на 8 утра)
2021-12-28 2021-12-28 0.22 Реализация функций хранения в EEPROM данных про заведённый будильник 2021-12-28 0.22 Рисование иконки будильника 2021-12-28 0.22 Экран настройки будильника теперь настраивает будильни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
    [1ModeWatchFace.ino, Display.ino, MelodyPlayer.ino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]
2021-12-29 2021-12-29 0.23 Исправлено: при смене настроек будильника скорее всего будет срабатывать будильник 2021-12-29 0.23 Исправлено: при смене времени скорее всего будет срабатывать будильник 2021-12-29 0.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
    [1ModeWatchFace.ino, 1WatchFace1.ino, 1WatchFace2.ino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]
2021-12-31 2021-12-30 0.24 Точечная оптимизация памяти 29446 - 28906 2021-12-30 0.24 Добавлен циферблат 3
2022-01-01 2021-12-31 1.00 Добавлен циферблат 4 2022-01-01 1.00 Точечная оптимизация памяти 29504 - 29312 2022-01-01 1.00 Реализовано "зрада" 2022-01-01 1.00 Удалено из меню: "свастон" 2022-01-01 1.00 Добавлен 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
2022-01-04 2022-01-04 1.01 Переименованы циферблаты 2022-01-04 1.01 Siemens перерисован 2022-01-04 1.01 Исправлено воскресенье 2022-01-04 1.01 украсившена анимация загрузки 2022-01-04 1.01 украсившена анимация 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
    [1ModeWatchFace.ino, 1WatchFace3.ino, Display.ino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]
2022-01-07 2022-01-05 1.02 Циферблат 3: Расстановка значков MeltemiOS 2022-01-05 1.02 Циферблат 2: расположение значков динамическое 2022-01-05 1.02 Анимация входа циферблат 1 2022-01-05 1.02 Анимация входа циф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
    [1ModeWatchFace.ino, 1WatchFace1.ino, 1WatchFace2.ino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]
2022-01-10 2022-01-10 1.03 Много комментариев в файле дисплея 2022-01-10 1.03 Обновлена икнока будильника (by meltemios) 2022-01-10 1.03 Исправлено: из меню выбора циферблатов нельзя выйти 2022-01-10 1.03 Перед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
    [1ModeWatchFace.ino, 1WatchFace1.ino, 1WatchFace2.ino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]
2022-01-12 2022-01-11 1.05 Немного оптимизации памяти: 29940 -> 29930 -> 29940 -> 29900 -> 29834 -> 29770 -> 29698 -> 29632 -> 29610 -> 29446
2022-01-12 2022-01-11 1.05 Немного оптимизации памяти: 29940 -> 29930 -> 29940 -> 29900 -> 29834 -> 29770 -> 29698 -> 29632 -> 29610 -> 29446 -> 29416 2022-01-11 1.05 Начата реализация циферблата Nokia
2022-01-13 2022-01-12 1.06 Много изменений по архитектуре программы 2022-01-13 1.06 Много изменений по архитектуре программы 2022-01-13 1.06 Начаты классы Generic, Display
    [DRMW2_NoFrames.drl, DRMW2_NoFrames_copper_bottom.gbr, DRMW2_NoFrames_copper_top.gbr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]
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2022-01-16 2022-01-16 1.07 Исправлено попердоливание циферблатов DRM Lite, Zubat. DRM Watch пока в анабиозе. 2022-01-16 1.07 Исправлено попердоливание графики 2022-01-16 1.07 Исправлено попердоливание экрана ст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
    [DRMW2_NoFrames.drl, DRMW2_NoFrames_copper_bottom.gbr, DRMW2_NoFrames_copper_top.gbr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]
2022-01-16 2022-01-16 1.07 Исправлено попердоливание циферблатов DRM Lite, Zubat. DRM Watch пока в анабиозе. 2022-01-16 1.07 Исправлено попердоливание графики 2022-01-16 1.07 Исправлено попердоливание экрана ст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
    [1ModeWatchFace.ino, Display.cpp, Generic.h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]
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2022-01-19 2022-01-18 1.08 Battery вынесен в класс 2022-01-18 1.08 RTC вынесен в класс 2022-01-18 1.08 Buzzer вынесен в класс 2022-01-18 1.08 EEPROM вынесен в класс 2022-01-19 1.08 Константы вынесены в Generic.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
    [1ModeWatchFace.ino, Buzzer.cpp, Buzzer.ino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]
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2022-01-21 2022-01-21 1.10 Исправлено: Выбор мелодии там пиздец 2022-01-21 1.10 Экран выбора циферблата отображает список циферблатов из массива 2022-01-21 1.10 Защита от перезагрузок если нет ни одного цифербл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
    [1ModeWatchFace.ino, Buzzer.cpp, Display.cpp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]
2022-01-25 2022-01-20 1.11 Циферблат Zubat перенесено в класс 2022-01-20 1.11 Переход циферблатов как ООП 2022-01-20 1.11 Обновлено начертание 7ки 2022-01-20 1.11 Начата реализация циферблата Xelibri 2022-01-25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
    [Back Case v8.step, Back Case v8.stl]
2022-01-29 2022-01-26 1.12 Обновлен формат даты на циферблате Xelibri 2022-01-26 1.12 Подвинул цифры на 1 пиксель 2022-01-26 1.12 Убрал иконки с экрана кселибри 2022-01-27 1.12 Начаты эксперименты с главным меню
    [2022-01-22 Back v8.stl.stl, 2022-01-26 Front No Chamfer v14.stl, 2022-01-26 Front No Chamfer v16.stl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]
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2022-02-13 2022-02-13 1.14 Инверсия перерисовка элементов на экране будильник 2022-02-13 1.14 В меню приложений пункт назад перенесено наверх 2022-02-13 1.14 В меню мелоий пункт назад перенесено наверх 2022-02-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
    [2022-02-13 Front No Chamfer v18.stl]
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2022-02-22 2022-02-15 1.16 Начата реализация циферблата матрица, добавлено 1,2 2022-02-16 1.16 Продолжаю делать циферблат матрица, добавлено 3,4 2022-02-17 1.16 Продолжаю делать циферблат матрица, добавлено 5,6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
    [2022-02-19 Back v20.3mf, 2022-02-19 Back v21.3mf]
2022-02-23 2022-02-23 1.17 Переразмещено меню настроек 2022-02-23 1.17 в код обработки длительного нажатия добавлен дебоунс 2022-02-23 1.17 Исправлена особенность когда при зажатии кнопки при возврате на циферб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
    [1ModeWatchFace.ino, GenericMenu.ino, ModeMenuMain.ino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]
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2022-02-25 2022-02-24 1.19 Исправлено попердоленный секундомер
    [ModeStopwatch.ino]
2022-02-25 2022-02-24 1.19 Исправлено попердоленный секундомер 2022-02-25 1.19 Добавляю функции пиксельний работы с дисплеем 2022-02-25 1.19 Переименование файлов 2022-02-25 1.19 Повішен приоритет подсветки в о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
    [Display.cpp, ModeWatchFace.ino, _DRMWatch2.ino]
2022-02-27 2022-02-25 1.19 Реализован циферблат с клеточным автоматом "жизнь" 2022-02-25 1.19 Исправлено: main меню если зажать кнопку то не перерисовывается экран 2022-02-25 1.19 Исправлено: Никак не могу реши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
    [GenericMenu.ino, ModeAbout.ino, ModeMenuMain.ino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]
2022-02-27 2022-02-24 1.19 Исправлено попердоленный секундомер 2022-02-25 1.19 Добавляю функции пиксельний работы с дисплеем 2022-02-25 1.19 Переименование файлов 2022-02-26 1.19 Повішен приоритет подсветки в о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
    [ModeWatchFace.ino]
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2022-09-18 Updated board
    [2022-09-10 DRMW2_BOARD_20mm.drl, 2022-09-10 DRMW2_BOARD_20mm_copper_bottom.gbr, 2022-09-10 DRMW2_BOARD_20mm_copper_top.gbr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]
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2022-11-09 2022-11-09 1.31 Добавлена в прошивку мелодия blue 2022-11-09 1.31 Обновления на экране "Справка"
    [2022-10-06 Back v35.stl, 2022-10-06 Front v35.stl, 2022-10-12 Back v38.stl]
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2023-03-12 2023-03-12 изменен порядок загрузки таким образом, чтобы мелодия играла до инициализации часов board V7: перемычка для подключения USB на батку (дебаг) подтяжка к 5В RST дополнены полиготы кнопок
    [2022-09-10 DRMW2_BOARD_20mm.drl, 2022-09-10 DRMW2_BOARD_20mm_copper_bottom.gbr, 2022-09-10 DRMW2_BOARD_20mm_copper_top.gbr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]
2023-04-11 Case and photos update
    [2023-04-08 Back-FDM-v60.stl, 2023-04-08 Front-FDM-v57.stl, Back Case v66.3mf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]
2023-04-15 Відмова від ООП для оптимізації пам'яті Доповнено екран про програму переписано спосіб збереження в коді циферблату
    [Back Case v80.stl]
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2023-04-19 documentation update
    [Back Case FDM v80.stl, Back Case v80.stl, BottomCover FDM v85.stl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]
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
